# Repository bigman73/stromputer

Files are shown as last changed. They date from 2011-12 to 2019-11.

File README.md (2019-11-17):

# stromputer

V-Strom + Computer --> Stromputer!
An Arduino based project, that adds the following features to a Mk1 (2004-2011) Suzuki V-Strom Motorcycles (DL650, DL1000)

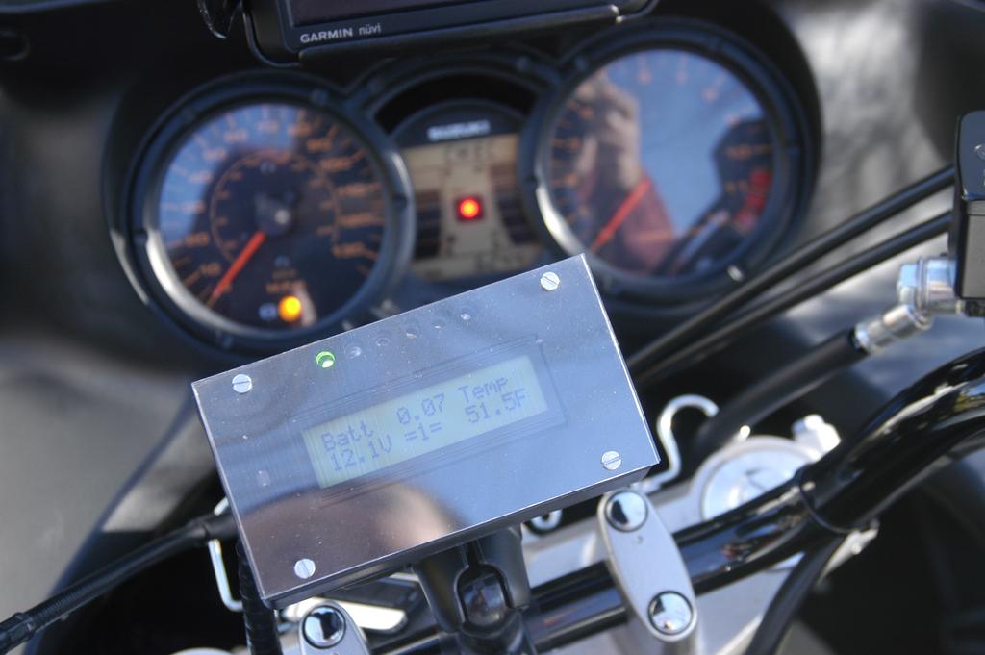
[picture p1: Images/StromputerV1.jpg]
Stromputer V1 installation of a 2011 Suzuki V-Strom 650


## Features

* Auxiliary LCD display that can reside on the handle bar
* Automatic adjustment of LCD display back light using a photo sensor (i.e. at darkness dim LCD display, at full bright day brighten display)
* Show battery level indicator in volts (LCD)
* Show ambient/air temperature (F or C) (LCD)
* Digital LCD Display of gear position
* Analog display of gear position using 6 LEDs
* Configuration and diagnostics shell (command line), with a laptop and USB using Putty or Arduino IDE - can be done while bike is running!
* Upgrade of Firmware through USB port - can also be done while bike is running.
* Modular platform, can be adapted for other motorcycles.

DIY Cost: About $70! (in a full water resistant enclosure)
Compare that to commercial gear indicators/battery indicator/temperature gauges.

Current status: Fully Functional (V1.09 - As of 2/7/2013)

## References
### Brickuino
[Brickuino](http://k75retro.blogspot.com/2014/02/) is a spin off project for BMW K75 Brick motorcycle, based on Stromputer
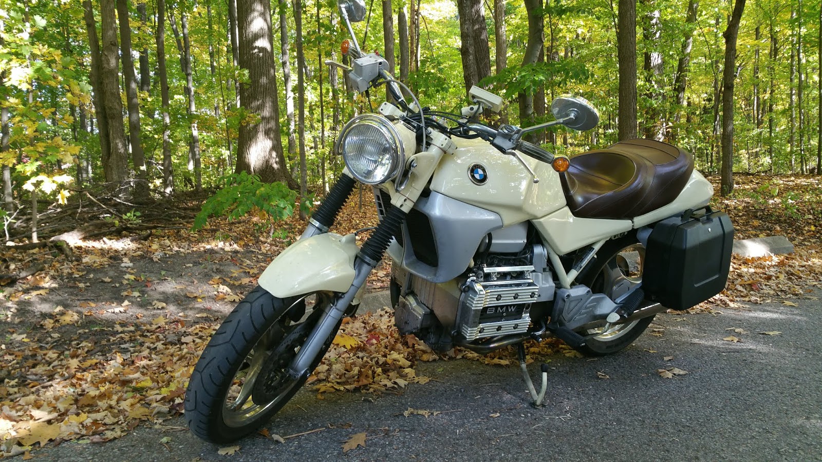
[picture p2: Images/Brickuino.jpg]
Brickuino BMW K75


## License 

Attribution-NonCommercial-ShareAlike 3.0 Unported (CC BY-NC-SA 3.0)

http://creativecommons.org/licenses/by-nc-sa/3.0/

You are free:
to Share — to copy, distribute and transmit the work

to Remix — to adapt the work

Under the following conditions:

+ Attribution — You must attribute the work in the manner specified by the author or licensor (but not in any way that suggests that they endorse you or your use of the work).

+ Noncommercial — You may not use this work for commercial purposes.
Share Alike — If you alter, transform, or build upon this work, you may distribute the resulting work only under the same or similar license to this one.

Creative Commons License

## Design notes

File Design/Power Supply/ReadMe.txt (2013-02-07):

All simulation files were generated using Linear Tech LTspice IV.  LTspice is a very capable analog circuit simulation based on the popular SPICE engine.

http://www.linear.com/designtools/software/

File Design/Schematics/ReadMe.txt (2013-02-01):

************PCB Design Software************************

All files for the PCB design were created in PCB Atrist.  To download this program go to:

http://www.4pcb.com/free-pcb-layout-software/

To view or modify the schematic open "Stromputer V1.sch" from PCB Artist.

To To view or modify the pcb open "Stromputer V1.pcb" from PCB Artist.

*************Component Libraries**********************

The component libraries used is this design were exported to "Stromputer.palib"

To import these components, simply drag and drop the file onto the Components page of the Library Manager dialog, or use the Add File button to browse to where the file is stored.
When you do this, each of the saved 'elements' (Component, PCB Symbols and/or Schematic Symbols) are stored in the special local libraries for Downloaded library items. From there, you can select them and use the Save Items To Library option to copy them to your own library files.

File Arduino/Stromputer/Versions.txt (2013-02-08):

// []
// []     **** Compatible with ARDUINO: 1.03 ****
// []
// []
// []   Versions:
// []     0.07 - Prototype, ADC worksonly with PCF8591
// []     0.08 - Prototype, ADC works with Arudino Analog or PCF8591
// []     0.09 - Prototype, add timed actions - Battery and Temperature should not be polled every loop, just once a few seconds
// []     0.10 - 12/3/2011, Stable Prototype, first version in Google Code/SVN
// []     0.11 - 12/4/2011, Added gear led logic in software, refactored code to use ISR for main board blink and gear neutral blinking led, changed welcome screen
// []     0.12 - 12/5/2011, Added direct gear emulation (tactile button)
// []     0.13 - 12/9/2011, Added gear led boot test. Last version compatible with Arduino 0023 before moving to Arduino 1.0
// []     0.14 - 12/9/2011, + All LED control was changed to use the LED Library,
// []                       + Add force LCD update every 15 seconds (workaround to LCD clearing screen from time to time)
// []                       + Fixed TimedAction to trigger immediately when sketch starts
// []     0.15 - 12/10/2011, + Changed custom Timer ISR to TimerOne library, Refactored all constants and variables to Stromputer.h header file
// []     0.16 - 12/10/2011, + Code refactoring, naming conventions
// []     0.17 - 12/10/2011 + Moved to Arduino 1.0 (.ino), Main loop slowed down to refersh on 4Hz, removed obsolete PCF8591 gear read logic
// []     0.18 - 12/13/2011 + Add Photo Cell read/Automatic LCD Backlight Adjustment
// []     0.19 - 12/24/2011 + Fixed forced refresh, lcd back light value now using average (for smoothing), Fixed temperature error handling
// []     0.20 - 12/25/2011 + LED Dimming, All LED pins changed to PWM
// []     0.21 - 12/26/2011 + Fixed minor bug - Neutral light was 'jumping' while light has been dimming.
// []     0.22 - 12/26/2011 + Adjusted real resistor values
// []     0.23 -   1/8/2012 + Added time action for checking forced LCD refresh, added serial messages when booting, Added initial Serial Input
// []     0.24 -   1/14/2012 + Added Serial Commands, removed serial debug
// []     0.25 -   1/14/2012 + Added Non-Volatile EEPROM configuration (remains after power is shut off, read when rebooting)
// []     0.26 -   1/21/2012 + Fixed I2C Error Handling, more EEPROM configurations
// []     0.27 -   1/22/2012 + Fixed some bugs - ISR was disabled on each serial processing, MILETONE: Successful 2ND deployment to V-Strom
// []     0.28 -   1/23/2012 + Fixed transient/fake Neutral
// []     0.30 -   2/1/2012  + 
// []     0.31 -   3/10/2012 + Fixed gear voltage ranges (measured on bike)
// []     0.40 -   3/29/2012 + Fixed ADC measuring error (battery and on-board temperature). VCC is not 5.0V and can change. Internal volt reference (1.1V) is used as a reference
// []                        + Using RunningAverage library for smoothing reading of input (Battery, Gear, Temperature)
// []     0.42 -   4/12/2012 + Gear ADC finally fixed - Resistors changed to 499KOhm military spec (low PPM, high precision).
// []     0.44 -   4/21/2012 + Restored VREF self learning mechanism
// []     1.00 -   5/20/2012 + Functional, no major issues
// []     1.02 -   8/11/2012 + Fixed gear voltage for 5th and 6h gear, larger gear and battery window sizes
// []     1.03 -   9/16/2012 + Fixed gear voltage
// []     1.04 -   12/15/2012 + Fine tuned LED factors
// []     1.05 -   12/29/2012 + Adaptions to new LCD display module (YwRobot, compatible to LiquidCrystal)
// []     1.06 -   1/17/2013  + Restored VCC calculation, instead of hard coded 5.0V (using Internal 1.1V reference), Moved to Arudino 1.0.3
// []     1.07 -   2/3/2013   + Compilation flags, fixed temperature labels position, fixed DS1631 initialization
// []     1.08 -   2/7/2013   + Added support for Sainsmart LCD Module
// []     1.09 -   2/7/2013   + Gear LEDs are now an option, enabled by the OPT_GEAR_LEDS #define
// []
// [][][][][][][][][][][][][][][][][][][][][][][][][][][][][][][][][][]

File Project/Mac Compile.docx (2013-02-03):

1) download Smart SVN

2) skip all the hokey initial run options. once you get the software open, click: <Project> <Check Out>

3) Paste the SVN url into the Repository field and hit continue

4) You should see this, with the trunk directory highlighted. Click Continue again

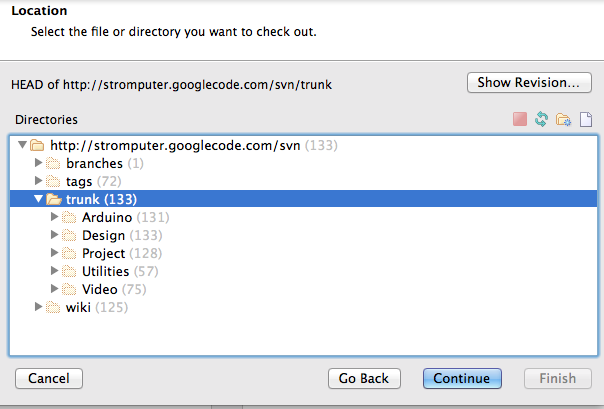
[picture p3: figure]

5)Decide where you want to save it locally.

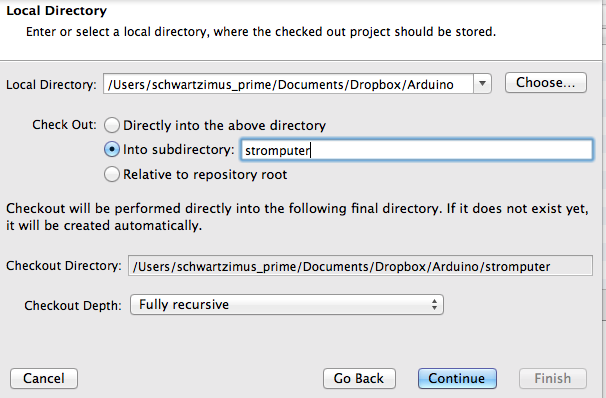
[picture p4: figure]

6) On the last screen, choose Export only since you're just downloading the files from the SVN, not actively working on them.

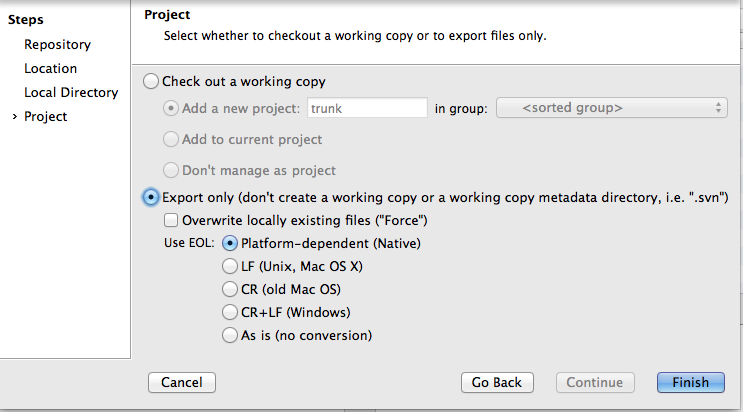
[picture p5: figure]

7) You need to get the included libraries into the proper location on the Mac.

a) Copy all the library folders you got from the SVN

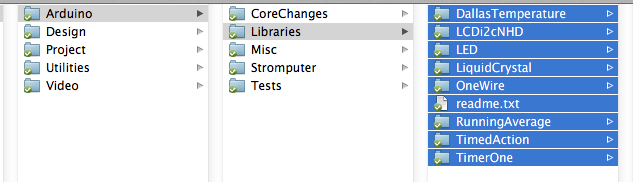
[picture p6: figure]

b) put them into the Mac's hidey-hole location for libraries in Documents/Arduino/Libraries

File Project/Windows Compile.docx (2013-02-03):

# Building Instructions for Stromputer V2

# Introduction

Stromputer V2 will be an improved design (i.e. evolution, not re-design) of Stromputer V1. It focuses on the following factors: 1. Reduced cost 2. Simpler design, less components 3. Smaller form factor

# Install Arduino

1. Download Arduino IDE (1.0+, recommended 1.0.3)

http://arduino.cc/en/Main/Software

1. Unzip the zip into a local folder - e.g. C:\Tools\arduino-1.0.3)

# Source Code Compiling

1. Checkout the code from Google Code: http://code.google.com/p/stromputer/source/checkout, into a local folder (e.g. C:\Development\Stromputer)
2. Delete the Arduino library LiquidCrystal? (http://code.google.com/p/stromputer/w/edit/LiquidCrystal) (e.g. C:\Tools\arduino-1.0.3\libraries\LiquidCrystal? (http://code.google.com/p/stromputer/w/edit/LiquidCrystal))
3. Copy all Stromputer 3rd Party libraries (C:\Development\stromputer\Arduino\Libraries) into Arduino folder (C:\Tools\arduino-1.0.3\libraries)
4. Run Arduino IDE
5. Open Stromputer sketch file (C:\Development\stromputer\Arduino\Stromputer\Stromputer.ino)
6. Compile all code by clicking on the Verify button

## Expected result

Code should compile without errors ("Done Compiling."), the last line in the output should be similar to this one, numbers may vary:

Binary sketch size: 23,688 bytes (of a 30,720 byte maximum)

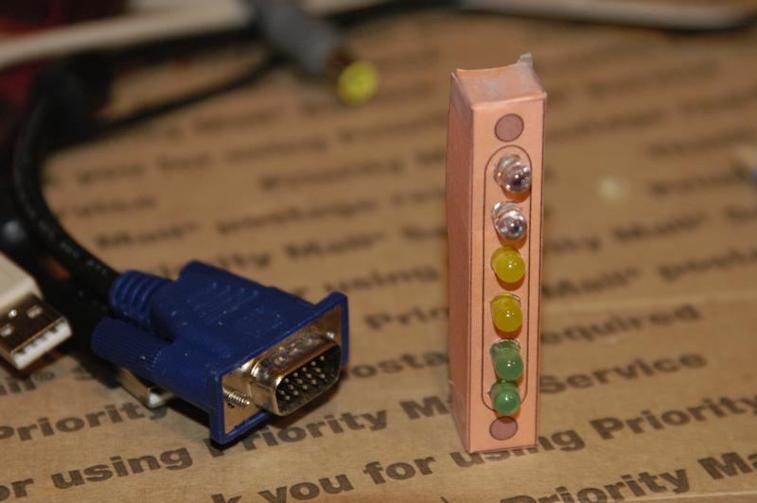
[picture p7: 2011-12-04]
Design/LED Case/mlNP4.jpg

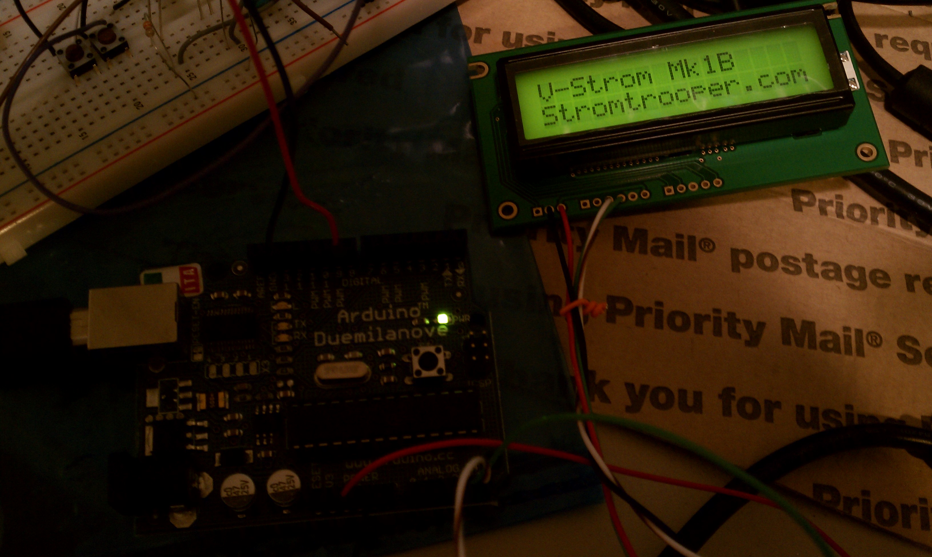
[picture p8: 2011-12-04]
Design/LCD Display/IMAG0272.jpg

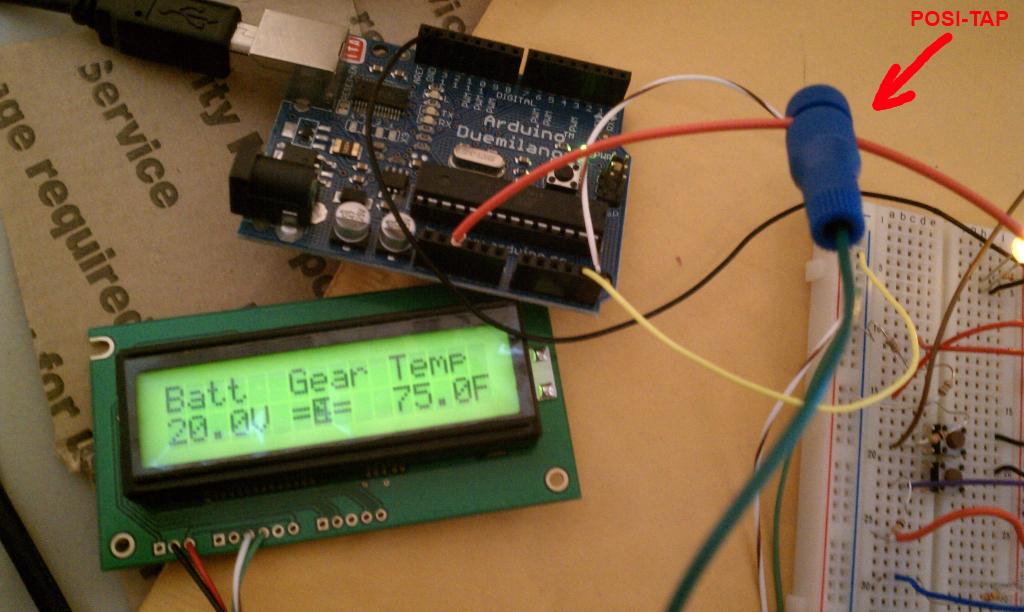
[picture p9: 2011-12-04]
Design/LCD Display/IMAG0290.jpg

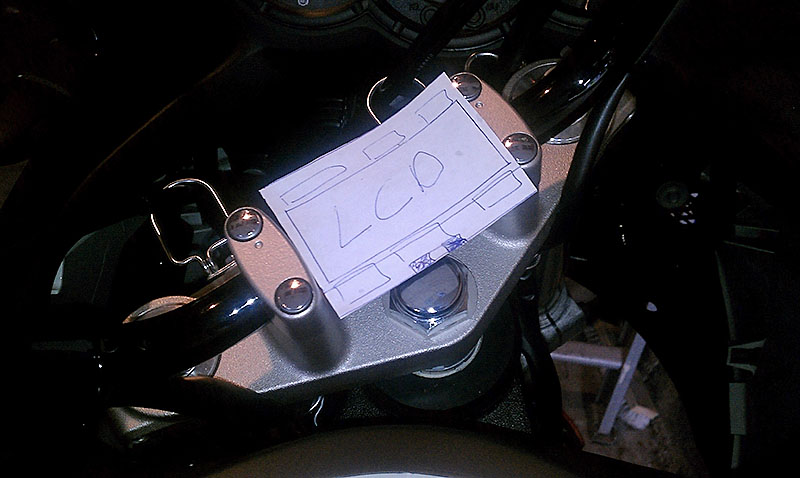
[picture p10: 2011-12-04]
Design/LCD Display/IMAG0016.jpg

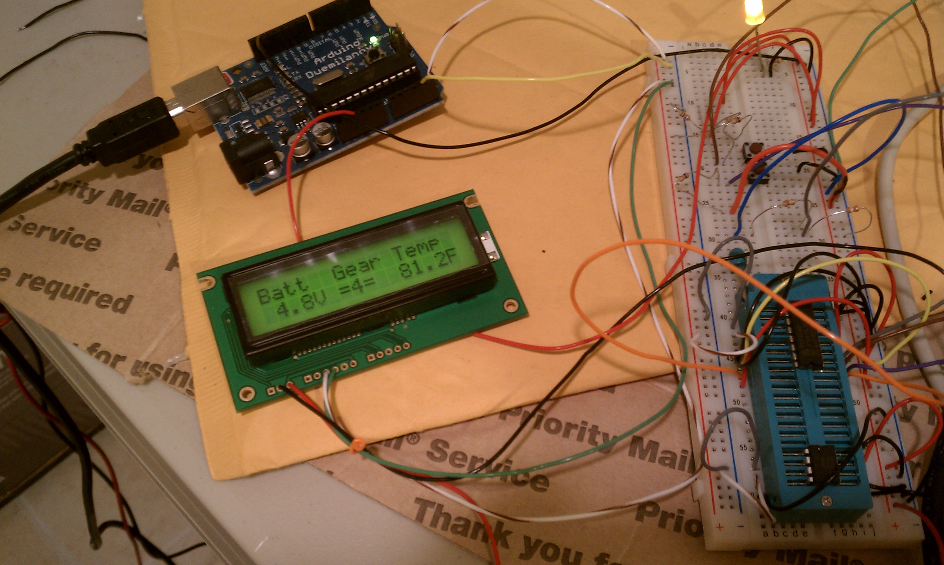
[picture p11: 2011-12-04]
Design/LCD Display/IMAG0280.jpg

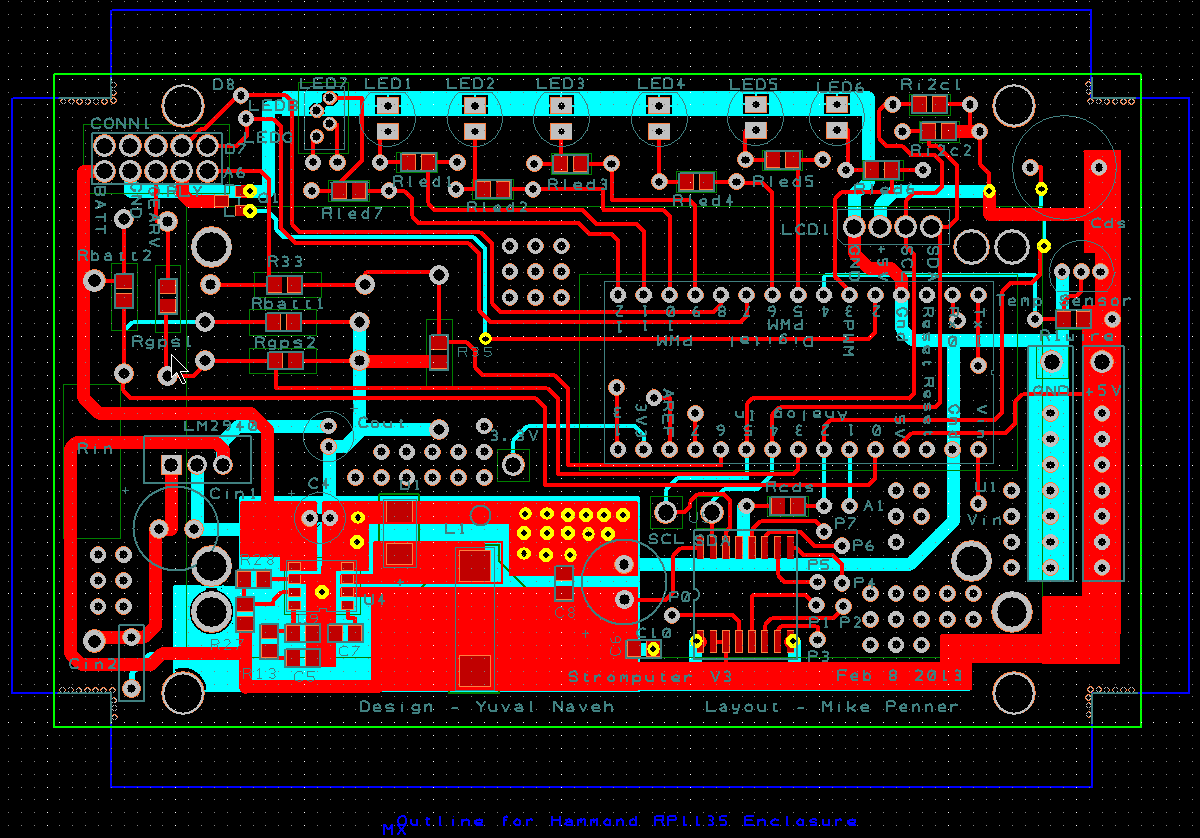
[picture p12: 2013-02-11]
Design/Schematics/PCB Design Stromputer V3.png

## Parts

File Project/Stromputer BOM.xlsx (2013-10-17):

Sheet: V3 (Final)
Component | Value | Manufacturer | Manufacturer Part No | Distributer | Distributer Part No | PCB Ref Name | Qty | Schematic Ref Name | Cost Per Unit | Cost | Notes
Arduino Nano V3 ATMEGA 328 |  |  | Iduino 328 | Amazon or Ebay | ASIN: B00ASSPI60 | U1 | 1 | Nano1 | $12.00 | $12.00 | Iduino is a tested 100% clone of Arduino Nano
10 Pin Header 18 AWG |  |  | -- | Amazon or Ebay | N/A | CONN1 | 1 | -- | $0.00 | $0.00 | Header should come with Iduino
1/8W Resistor | 1k | Stackpole | CF18JT1K00 | Digikey | CF18JT1K00CT-ND | R15 | 1 | Rled1 | $0.09 | $0.09 | LED Resistor
1/8W Resistor | 1k | Stackpole | CF18JT1K00 | Digikey | CF18JT1K00CT-ND | R16 | 1 | Rled2 | $0.09 | $0.09 | LED Resistor
1/8W Resistor | 1k | Stackpole | CF18JT1K00 | Digikey | CF18JT1K00CT-ND | R17 | 1 | Rled3 | $0.09 | $0.09 | LED Resistor
1/8W Resistor | 1k | Stackpole | CF18JT1K00 | Digikey | CF18JT1K00CT-ND | R18 | 1 | Rled4 | $0.09 | $0.09 | LED Resistor
1/8W Resistor | 1k | Stackpole | CF18JT1K00 | Digikey | CF18JT1K00CT-ND | R19 | 1 | Rled5 | $0.09 | $0.09 | LED Resistor
1/8W Resistor | 1k | Stackpole | CF18JT1K00 | Digikey | CF18JT1K00CT-ND | R20 | 1 | Rled6 | $0.09 | $0.09 | LED Resistor
1/8W Resistor | 4.7k | Stackpole | CF18JT4K70 | Digikey | CF18JT4K70CT-ND | R21 | 1 | R1wire | $0.09 | $0.09 | OneWire Pullup Resistor
1/8W Resistor | 4.7k | Stackpole | CF18JT4K70 | Digikey | CF18JT4K70CT-ND | R37 | 1 | Ri2c1 | $0.09 | $0.09 | I2C Pullup Resistor
1/8W Resistor | 4.7k | Stackpole | CF18JT4K70 | Digikey | CF18JT4K70CT-ND | R38 | 1 | Ri2c2 | $0.09 | $0.09 | I2C Pullup Resistor
1/8W Resistor | 10k | Stackpole | CF18JT10K0 | Digikey | CF18JT10K0CT-ND | R14 | 1 | Rcds | $0.09 | $0.09 | Resistor (Voltage Divider)
1/2W Mil Spec Resistor | 953k | Vishay Dale | CMF55953K00BEEB | Digikey | CMF953KHBCT-ND | R23 | 1 | Rbatt2 | $1.53 | $1.53 | Resistor (Voltage Divider)
1/2W Mil Spec Resistor | 332k | Vishay Dale | CMF55332K00BEEB | Digikey | CMF332KHBCT-ND | R26 | 1 | Rbatt1 | $1.12 | $1.12 | Resistor (Voltage Divider)
1/2W Mil Spec Resistor | 499k | Vishay Dale | CMF55499K00BEEB | Digikey | CMF499KHBCT-ND | R24 | 2 | Rgps1, Rgps2 | $1.12 | $2.24 | Resistor (Voltage Divider)
CAPP Pan 8 mm body | 220uF | Panasonic | ECA-1EHG221 | Digikey | P5541-ND | C2 | 1 | Cin1 | $0.45 | $0.45 | Capacitor (Linear Regulator)
CAP TDK Cer Radial | 0.47uF | TDK | FK26X7R1H474K | Digikey | 445-2870-ND | C3 | 1 | Cin2 | $0.48 | $0.48 | Capacitor (Linear Regulator)
CAPP Pan AL 5 mm body | 22uF | Panasonic | EEU-FM1H220 | Digikey | P12927-ND | C1 | 1 | Cout | $0.31 | $0.31 | Capacitor (Linear Regulator)
DS18B20-TO92 |  | Maxim Integrated | DS18B20+T&R | Digikey | DS18B20+T&RCT-ND | U2 | 1 | Temp Sensor | $4.51 | $4.51 | I2C Digital Temperature Sensor
LCD 16x2 NHD |  | NHD | NHD-0216K3Z-FL-GBW-V3 | Digikey | NHD-0216K3Z-FL-GBW-V3-ND | LCD1 | 1 | LCD1 | $19.75 | $19.75 | LCD (I2C). See Note 1 below
LED | Blue | Cree | C503B-BCS-CV0Z0461 | Digikey | C503B-BCS-CV0Z0461-ND | LED6 | 1 | Led1 | $0.21 | $0.21 | BLUE LED - Gear 6
LED | Green | Cree | C503B-GCN-CY0C079 | Digikey | C503B-GCN-CY0C0791-ND | LED1 | 1 | Led2 | $0.24 | $0.24 | GREEN LED - Gear 1
LED | Yellow | Lumex Opto | SSL-LX5093YT | Digikey | 67-1117-ND | LED2 LED3 | 2 | Led3,Led4 | $0.55 | $1.10 | YELLOW LED - Gear 2,3
LED | White | Cree | C503B-WAN-CCACB151 | Digikey | C503B-WAN-CCACB151-ND | LED4 LED5 | 2 | Led5, Led6 | $0.46 | $0.92 | WHITE LED - Gear 4,5
LM2940T-5.0 |  | TI | LM2940T-50 | Digikey | LM2940T-5.0-ND | U3 | 1 | LM2940 | $1.68 | $1.68 | 12V->5V linear voltage regulator
3W Resistor | 16 | Panasonic | ERG-3SJ160 | Digikey | P16W-3BK-ND | R22 | 1 | Rin | $0.59 | $0.59 | Current Limiter Resistor, Linear Regulator
PDV-P8001 |  | Advanced Photonix | PDV-P8001 | Digikey | PDV-P8001-ND | VR1 | 1 | Cds | $1.86 | $1.86 | Photo sensor
Enclosure |  | Hammond | RP1135C | Digikey | RP1135C-ND |  | 1 |  | $8.57 | $8.57 | Water Proof Clear Top Enclosure
Custom PCB |  |  |  | Stromtrooper/Bigman73 |  |  | 1 |  | $15.00 | $15.00
 |  |  |  |  |  |  |  |  | Total cost | $73.46
Notes:
1. There are cheaper LCD modules, e.g. from eBay/Amazon or other internet sources, but they do not support programmatic constast and brightness control.
The SainSmart and YwRobot 1602 I2C modules have been certificed to work with the Stromputer firmware, and the firmware now supports them
LCD 16x2 I2C |  | SainSmart | LCD 1602 I2C | Amazon | ASIN: B00813HBEQ | LCD1 | 1 |  | $13.50 | $13.50 | Alternative to NHD LCD Module

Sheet: V3 (Full All Options)
Component | Package | Value | Manuf | Manuf Part No | Distrib | Distrib Part No | PCB Ref Name | Qty | Schematic Ref Name | Cost Per Unit | Cost | Notes
Arduino Nano V3 ATMEGA 328 | USER |  |  |  | Amazon or Ebay | ASIN: B00ASSPI60 | U1 | 1 | Nano1 | $12.00 | $12.00 | Iduino is a tested 100% clone of Arduino Nano
10 Pin Header 18 AWG | USER |  |  |  | Amazon or Ebay | N/A | CONN1 | 1 |  | $0.00 | $0.00 | Header should come with Iduino
1/8W Resistor | USER | 1k | Stackpole | CF18JT1K00 | Digikey | CF18JT1K00CT-ND | R15 | 1 | Rled1 | $0.09 | $0.09 | LED Resistor
1/8W Resistor | USER | 1k | Stackpole | CF18JT1K00 | Digikey | CF18JT1K00CT-ND | R16 | 1 | Rled2 | $0.09 | $0.09 | LED Resistor
1/8W Resistor | USER | 1k | Stackpole | CF18JT1K00 | Digikey | CF18JT1K00CT-ND | R17 | 1 | Rled3 | $0.09 | $0.09 | LED Resistor
1/8W Resistor | USER | 1k | Stackpole | CF18JT1K00 | Digikey | CF18JT1K00CT-ND | R18 | 1 | Rled4 | $0.09 | $0.09 | LED Resistor
1/8W Resistor | USER | 1k | Stackpole | CF18JT1K00 | Digikey | CF18JT1K00CT-ND | R19 | 1 | Rled5 | $0.09 | $0.09 | LED Resistor
1/8W Resistor | USER | 1k | Stackpole | CF18JT1K00 | Digikey | CF18JT1K00CT-ND | R20 | 1 | Rled6 | $0.09 | $0.09 | LED Resistor
1/8W Resistor | USER | 4.7k | Stackpole | CF18JT4K70 | Digikey | CF18JT4K70CT-ND | R21 | 1 | R1wire | $0.09 | $0.09 | OneWire Pullup Resistor
1/8W Resistor | USER | 4.7k | Stackpole | CF18JT4K70 | Digikey | CF18JT4K70CT-ND | R37 | 1 | Ri2c1 | $0.09 | $0.09 | I2C Pullup Resistor
1/8W Resistor | USER | 4.7k | Stackpole | CF18JT4K70 | Digikey | CF18JT4K70CT-ND | R38 | 1 | Ri2c2 | $0.09 | $0.09 | I2C Pullup Resistor
1/8W Resistor | USER | 10k | Stackpole | CF18JT10K0 | Digikey | CF18JT10K0CT-ND | R14 | 1 | Rcds | $0.09 | $0.09 | Resistor (Voltage Divider)
1/2W Mil Spec Resistor | USER | 953k | Vishay Dale | CMF55953K00BEEB | Digikey | CMF953KHBCT-ND | R23 | 1 | Rbatt2 | $1.53 | $1.53 | Resistor (Voltage Divider)
1/2W Mil Spec Resistor | USER | 332k | Vishay Dale | CMF55332K00BEEB | Digikey | CMF332KHBCT-ND | R26 | 1 | Rbatt1 | $1.12 | $1.12 | Resistor (Voltage Divider)
1/2W Mil Spec Resistor | USER | 499k | Vishay Dale | CMF55499K00BEEB | Digikey | CMF499KHBCT-ND | R24 | 2 | Rgps1, Rgps2 | $1.12 | $2.24 | Resistor (Voltage Divider)
CAPP Pan 8 mm body | USER | 220uF | Panasonic | ECA-1EHG221 | Digikey | P5541-ND | C2 | 1 | Cin1 | $0.45 | $0.45 | Capacitor (Linear Regulator)
CAP TDK Cer Radial | DSC | 0.47uF | TDK | FK26X7R1H474K | Digikey | 445-2870-ND | C3 | 1 | Cin2 | $0.48 | $0.48 | Capacitor (Linear Regulator)
CAPP Pan AL 5 mm body | DSCV | 22uF | Panasonic | EEU-FM1H220 | Digikey | P12927-ND | C1 | 1 | Cout | $0.31 | $0.31 | Capacitor (Linear Regulator)
DS18B20-TO92 | DSC |  | Maxim Integrated | DS18B20+T&R | Digikey | DS18B20+T&RCT-ND | U2 | 1 | Temp Sensor | $4.51 | $4.51 | I2C Digital Temperature Sensor
LCD 16x2 NHD | USER |  | NHD | NHD-0216K3Z-FL-GBW-V3 | Digikey | NHD-0216K3Z-FL-GBW-V3-ND | LCD1 | 1 |  | $19.75 | $19.75 | LCD (I2C)
LED | DSC | Blue | Cree | C503B-BCS-CV0Z0461 | Digikey | C503B-BCS-CV0Z0461-ND | LED6 | 1 |  | $0.21 | $0.21 | BLUE LED - Gear 6
LED | DSC | Green | Cree | C503B-GCN-CY0C079 | Digikey | C503B-GCN-CY0C0791-ND | LED1 | 1 |  | $0.24 | $0.24 | GREEN LED - Gear 1
LED | DSC | Yellow | Lumex Opto | SSL-LX5093YT | Digikey | 67-1117-ND | LED2 LED3 | 2 |  | $0.55 | $1.10 | YELLOW LED - Gear 2,3
LED | DSC | White | Cree | C503B-WAN-CCACB151 | Digikey | C503B-WAN-CCACB151-ND | LED4 LED5 | 2 |  | $0.46 | $0.92 | WHITE LED - Gear 4,5
LM2940T-5.0 | T03B |  | TI | LM2940T-50 | Digikey | LM2940T-5.0-ND | U3 | 1 | LM2940 | $1.68 | $1.68 | 12V->5V linear voltage regulator
3W Resistor | USER | 16 | Panasonic | ERG-3SJ160 | Digikey | P16W-3BK-ND | R22 | 1 | Rin | $0.59 | $0.59 | Current Limiter Resistor, Linear Regulator
PDV-P8001 | USER |  | Advanced Photonix | PDV-P8001 | Digikey | PDV-P8001-ND | VR1 | 1 | Cds | $1.86 | $1.86 | Photo sensor
Enclosure |  |  | Hammond | RP1085C | Digikey | RP1085C-ND |  | 1 |  | $8.57 | $8.57 | Water Proof Clear Top Enclosure
Custom PCB |  |  |  |  | Stromtrooper/Bigman73 |  |  | 1 |  | $11.00 | $11.00 | $5 raw cost + $6 shipping
 |  |  |  |  |  |  |  |  |  | Total cost | $69.46
OPTIONAL - ALTERNATIVE |  | SM |  |  |  | Mouser |  | R35 | 1
 | LED RGB WP154 | USER |  | Kingbright | WP154A4SUREQBFZGC | Digikey | 754-1615-ND | LED7 | 1 |  |  |  | RGB LED
 | LM358 MSOP8 DGK Non Comp Side | MSOP8 DGK |  |  |  |  |  | U7 | 1
 | PCF8574T SOIC16W MS-013 | SM |  |  |  |  |  | U5 | 1 |  |  |  | ADC/DAC I2C extender
 | PCF8591 SOIC16W | SM |  |  |  |  |  | U6 | 1 |  |  |  | IO I2C Extender
 | RES 0805 | SM | 1K | Panasonic | ERA-6AED102V | Mouser | 667-ERA-6AED102V | R1 | 1 | Rled1 Alt
 |  | SM |  | Panasonic | ERA-6AED102V | Mouser | 667-ERA-6AED102V | R2 | 1 | Rled2 Alt
 |  | SM |  | Panasonic | ERA-6AED102V | Mouser | 667-ERA-6AED102V | R3 | 1 | Rled3 Alt
 |  | SM |  | Panasonic | ERA-6AED102V | Mouser | 667-ERA-6AED102V | R4 | 1 | Rled4 Alt
 |  | SM |  | Panasonic | ERA-6AED102V | Mouser | 667-ERA-6AED102V | R5 | 1 | Rled5 Alt
 |  | SM |  | Panasonic | ERA-6AED102V | Mouser | 667-ERA-6AED102V | R6 | 1 | Rled6 Alt
 |  | SM |  | Panasonic | ERA-6AED102V | Mouser | 667-ERA-6AED102V | R31 | 1 | Rled7 Alt
 | RES 0805 | SM | 4.7k | Panasonic | CRCW08054K70JNEA | Mouser | 71-CRCW0805J-4.7K-E3 | R11 | 1 | R1wire Alt
 |  | SM |  | Panasonic | ERJ-6GEYJ472V | Mouser | ERJ-6GEYJ472V | R29 | 1 | Ri2c1 Alt
 |  | SM |  | Panasonic | ERJ-6GEYJ472V | Mouser | ERJ-6GEYJ472V | R30 | 1 | Ri2c2 Alt
 | RES 0805 | SM | 10k | Panasonic | ERJ-6GEYJ103V | Mouser | 667-ERJ-6GEYJ103V | R12 | 1 | Rcds Alt
 | RES 0805 | SM | 12.1k | Panasonic | ERJ-6ENF1212V | Digikey | P12.1KCCT-ND | R28 | 1
 | RES 0805 | SM | 22k | Panasonic | ERJ-6GEYJ223V | Digikey | P22KACT-ND | R13 | 1
 | RES 0805 | SM | 36.5k | Panasonic | ERJ-6ENF3652V | Digikey | P36.5KCCT-ND | R27 | 1
 | RES 0805 | SM | 332k | Panasonic | ERA-6AEB3323V | Mouser | 667-ERA-6AEB3323V | R9 | 1 | Rbatt1 Alt
 | RES 0805 | SM | 499k | Panasonic | ERA-6AEB4993V | Mouser | 667-ERA-6AEB4993V | R7 | 1 | Rgps1 Alt
 |  | SM |  | Panasonic | ERA-6AEB4993V | Mouser | 667-ERA-6AEB4993V | R8 | 1 | Rgps2 Alt
 | RES 0805 | SM | 953k | Panasonic | ERA-6AED9533V | Mouser | 667-ERA-6AED9533V | R10 | 1 | Rbatt2 Alt
 | RES 0805 Non Comp Side | SM |  |  |  |  |  | R39 R40 R41 R42 | 4
 | Si2304BDS MOSFET | USER |  | Vishay | SI2304BDS-T1-GE3 | Digikey | SI2304BDS-T1-GE3CT-ND | Q1 | 1
 | LT1776 SO8N | SM |  | Linear Tech | LT1776CS8#PBF | Digikey | LT1776CS8#PBF-ND | U4 | 1 |  |  |  | Switching voltage regulator
 | MBRS1100 | SM |  | Vishay | MBRS1100TRPBF | Digikey | MBRS1100TRPBFCT-ND | D1 | 1 |  |  |  | Schottky Rectifier (switching regulator)
 | RES 0805 | SM |  |  |  |  |  | R34 | 1
 | 1/8W Resistor | USER | 1k | Stackpole | CF18JT1K00 | Digikey | CF18JT1K00CT-ND | R32 | 1 | Rled7 | 0.09 | $0.09 | Resistor - Optional, not supported as of V2, but will be supported in a future firmware
 |  | DSCV |  | Panasonic | EEU-FM1H220 | Digikey | P12927-ND | C4 | 1 |  |  |  | Capacitor (Switching Regulator)
 | CAP 0805 | SM | 2200 pF | Murata | GRM2165C1H222JA01D | Digikey | Digikey | C5 | 1 |  |  |  | Capacitor (Switching Regulator)
 | CAP 0805 | SM | 2.2 uF | Murata | GRM21BF51A225ZA01L | Digikey | 490-1743-1-ND | C8 | 1 |  |  |  | Capacitor (Switching Regulator)
 | CAP 0805 | SM | 100 pF | Murata | GRM2165C1H101JA01D | Digikey | 490-1615-1-ND | C7 C9 | 2 |  |  |  | Capacitor (Switching Regulator)
 | Ind Bourns SDR1005 | USER | 100 uH | Bourns | SDR1005-101KL | Digikey | SDR1005-101KLCT-ND | L1 | 1 |  |  |  | Inductor (Switching Regulator)
 | CAPP Pan 8 mm body | USER | 220uF | Panasonic | ECA-1EHG221 | Digikey | P5541-ND | C10 | 1 |  |  | $0.00 | Capacitor (Switching Regulator)
 | 1/2W Resistor | USER |  |  |  |  |  | R33 R36 | 2 |  |  | $0.00 | Generic Voltage Divider *Unused*
 | CAP 0805 | SM | 0.1 uF |  |  |  |  | C6 C11 | 2 |  |  | $0.00 | Capacitor - PCF8591/PCF8574
 | CAP 0805 Non Comp Side | SM | 0.1 uF |  |  |  |  | C12 | 1 |  |  | $0.00 | Capacitor (OP-AMP)

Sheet: V2
 | Stromputer BOM (Bill Of Materials) |  | GEN2
 | Number | Description | Schematic Name | Part # | Qty | Unit Price | Price | Link | Purpose
Microcontroller | 1 | Arduino Nano V3 (or compatible) - ATMEGA328P (32K Flash) | Nano1 |  | 1 | $10 | $10.00 | ebay | Brain - Microcontroller
Power Supply | 3 | 16 Ohm current limiter | Rin | DIGIKEY: P16W-3BK-ND | 1 | $0.59 | $0.59 | http://www.digikey.com/product-detail/en/ERG-3SJ160/P16W-3BK-ND/36658 | Part of 12V->5V power regulator
 | 4 | LM2940 5V REGULATOR | LM2940 | DIGIKEY: LM2940T-5.0-ND | 1 | $1.89 | $1.89 | http://www.digikey.com/scripts/DkSearch/dksus.dll?WT.z_header=search_go&lang=en&x=21&y=17&cur=USD | Part of 12V->5V power regulator
 | 5 | Cin1 220uF capacitor | Cin1 | DIGIKEY: P5541-ND | 1 | $0.45 | $0.45 | http://www.digikey.com/scripts/DkSearch/dksus.dll?vendor=0&keywords=P5541-ND | Part of 12V->5V power regulator
 | 6 | Cin2 0.47uF ceramic capacitor | Cin2 | DIGIKEY: 445-2870-ND | 1 | $0.45 | $0.45 | http://www.digikey.com/scripts/DkSearch/dksus.dll?WT.z_header=search_go&lang=en&x=20&y=15&cur=USD | Part of 12V->5V power regulator
 | 7 | Cout 22uF alum capacitor | Cout | DIGIKEY: P12927-ND | 1 | $0.31 | $0.31 | http://www.digikey.com/scripts/DkSearch/dksus.dll?WT.z_header=search_go&lang=en&x=21&y=21&cur=USD | Part of 12V->5V power regulator
LEDs | 8 | Green Clear 5mm LED (for 1st gear) | Led1 | DIGIKEY: C503B-GCN-CY0C0791-ND | 1 | $0.23 | $0.23 | http://www.digikey.com/product-detail/en/C503B-GCN-CY0C0791/C503B-GCN-CY0C0791-ND/1922940 | Gear Position indicator | Note that these are only necessary if you want to color code your gears. If you want to have the same color for all gears then get all the same color LEDs.
 | 9 | Yellow Clear 5mm LED (for 2nd,3rd gears) | Led2, Led3 | DIGIKEY: 365-1183-ND | 2 | $0.19 | $0.38 | http://www.digikey.com/product-detail/en/OVLFY3C7/365-1183-ND/827119 | Gear Position indicator
 | 10 | White Clear 5mm LED (for 4th,5th gears) | Led4, Led5 | DIGIKEY: C503B-WAN-CCACB151-ND | 2 | $0.53 | $1.06 | http://www.digikey.com/scripts/DkSearch/dksus.dll?WT.z_header=search_go&lang=en&x=11&y=13&cur=USD | Gear Position indicator
 | 11 | Blue Clear 5mm LED (for 6th gear) | Led6 | DIGIKEY: C503B-BCS-CV0Z0461-ND | 1 | $0.18 | $0.18 | http://www.digikey.com/product-detail/en/C503B-BCS-CV0Z0461/C503B-BCS-CV0Z0461-ND/1922944 | Gear Position indicator
 | 12 | LED Resistors - 1KOhm, 1/8W | Rled1 .. Rled6 | *Generic | 6 | $0.15 | $0.90 |  | Limit current of Gear Position indicator LEDs
Photo Cell | 13 | PHOTOCELL (CdS) | Cds | DIGIKEY: PDV-P8001-ND | 1 | $1.86 | $1.86 | http://www.digikey.com/scripts/DkSearch/dksus.dll?WT.z_header=search_go&lang=en&x=17&y=15&cur=USD | Measures ambient light to control brightness of backlit LCD display and LEDs
 | 14 | PhotoCell Voltage Divider Resistor - 10KOhm, 1/8W | Rcds | *Generic | 1 | $0.15 | $0.15 |  | Part of PhotoCell circuit
Detect Gear | 15 | Gear Voltage Div Resistors - MilSpec - 499KOhm | Rgps1, Rgps2 | DIGIKEY: CMF499KHBCT-ND | 2 | $1.00 | $2.00 | http://www.digikey.com/product-detail/en/CMF55499K00BEEB/CMF499KHBCT-ND/2197183 | Part of gear voltage meter circuit
Measure Battery | 16 | Battery Voltage Div Resistor 1 - MilSpec - 332KOhm | Rbatt1 | DIGIKEY: CMF332KHBCT-ND | 1 | $1.00 | $1.00 | http://www.digikey.com/product-detail/en/CMF55332K00BEEB/CMF332KHBCT-ND/2197180 | Part of battery voltage meter circuit
 | 17 | Battery Voltage Div Resistor 2 - MilSpec - 953KOhm | Rbatt2 | DIGIKEY: CMF953KHBCT-ND | 1 | $1.00 | $1.00 | http://www.digikey.com/product-detail/en/CMF55953K00BEEB/CMF953KHBCT-ND/2197185 | Part of battery voltage meter circuit
LCD | 18 | I2C LCD Display (16x2) | LCD | EBAY | 1 | $10.00 | $10.00 | http://www.ebay.com/itm/IIC-I2C-TWI-1602-Serial-Shield-Modle-LCD-Display-For-Arduino-MEGA-2560-UNO-A004-/251052650605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 | Main Display
 | 19 | I2C Pull Up Resistors - 4.7KOhm, 1/8W | Ri2c | *Generic | 2 | $0.15 | $0.30 |  | Pulls up the LCD I2C SDA and SCL lines
Temp Sensor | 20 | DS18B20 I2C Temp Sensor | Temperature Sensor | EBAY | 1 | $1.60 | $1.60 | http://www.ebay.com/itm/1-PCS-DS18B20-18B20-Thermometer-Temperature-Sensor-Dalla-/170750980342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 | Digital Temperature Sensor
 | 21 | OneWire Pull Up Resistor - 4.7KOhm, 1/8W | Ronewire | *Generic | 1 | $0.15 | $0.15 |  | Part of digital temperature sensor circuit, pulls up the OneWire line
Hardware | 22 | Enclosure for LCD/LED display |  | DIGIKEY: HM1038-ND | 1 | $6.52 | $6.52 | http://www.digikey.com/scripts/DkSearch/dksus.dll?WT.z_header=search_go&lang=en&x=15&y=14&cur=USD | Enclosure (Box) to hold all components
 | 23 | Posi-Locks - 18-24 AWG (RED) |  | Posi-Lock | 3 | $3.00 | $9.00 | http://www.posi-lock.com/lock2.html | Optional - used to connect/disconnect wires quickly without soldering |  | Note that posi-lock products come in packages. Try to find cheaper single distributions, or buy with other stromtroopers are share the cost
 | 24 | Posi-Tap - 16-18 AWG (BLUE) |  | Posi-Tap | 1 | $9.00 | $9.00 | http://www.posi-lock.com/posiplug.html | Optional - used to tap into the V-Strom GPS (the pink wire)
 | 25 | Radio shack PCB 417 Holes |  | Model: 276-150 | Catalog #: 276-150 | 1 | $2.49 | $2.49 | http://www.radioshack.com/product/index.jsp?productId=2102845 | Circuit board to connect everything together.
 |  |  |  | Total Cost |  |  | $61.51

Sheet: V1 (OBSOLETE)
Stromputer BOM (Bill Of Materials)
Number | Description | Part # | Qty | Unit Price | Price | Link
1 | Arduino Duemilanove | ASIN: B001VK18HC | 1 | $27 | $27.00 | http://www.amazon.com/Arduino-Duemilanove/dp/B001VK18HC
2 | 14V Zener Diode | DIGIKEY: 1N5244B-TPCT-ND | 1 | $0.32 | $0.32
8 | 16Ohm current limiter | DIGIKEY: P16W-3BK-ND | 1 | $0.59 | $0.59
4 | LM2940 9V REGULATOR | DIGIKEY: LM2940T-9.0-ND | 1 | $1.89 | $1.89
5 | Cin1 220uF capacitor | DIGIKEY: P5541-ND | 1 | $0.45 | $0.45
6 | Cin2 0.47uF ceramic capacitor | DIGIKEY: 445-2870-ND | 1 | $0.45 | $0.45
7 | Cout 22uF alum capacitor | DIGIKEY: P12927-ND | 1 | $0.31 | $0.31
8 | Blue Clear 5mm LED (for 6th gear) | DIGIKEY: C503B-BCS-CV0Z0461-ND | 1 | $0.18 | $0.18
9 | Green Clear 5mm LED (for 1st gear) | DIGIKEY: C503B-GCN-CY0C0791-ND | 1 | $0.23 | $0.23
10 | White Clear 5mm LED (for 4th,5th gears) | DIGIKEY: C503B-WAN-CCACB151-ND | 2 | $0.53 | $1.06
11 | Yellow Clear 5mm LED (for 2nd,3rd gears) | DIGIKEY: 67-1117-ND | 2 | $0.40 | $0.80
12 | PHOTOCELL (CdS) | DIGIKEY: PDV-P8001-ND | 1 | $1.86 | $1.86
13 | NHD LCD Display (16x2) | DIGIKEY: NHD-0216B3Z-FL-GBW-ND | 1 | $19.95 | $19.95
14 | DS1631 I2C Temp Sensor | DIGIKEY: DS1631+-ND | 1 | $4.76 | $4.76
15 | Enclosure for LCD/LED display | DIGIKEY: HM1038-ND | 1 | $6.52 | $6.52
16 | Enclosure for Arduino | DIGIKEY: HM107-ND | 1 | $5.12 | $5.12
17 | Ethernet Dual Port | DIGIKEY: A31449-ND | 1 | $3.93 | $3.93
18 | ProtoScrewShield | SparkFun: DEV-09729 | 1 | $14.95 | $14.95 | http://www.sparkfun.com/products/9729
19 | LED Resistors - 1KOhm, 1/8W | * | 6 | $0.15 | $0.90
20 | I2C Pull Up Resistors - 10KOhm, 1/8W | * | 2 | $0.15 | $0.30
21 | PhotoCell Resistor - 10KOhm, 1/8W | * | 1 | $0.15 | $0.15
22 | Battery Voltage Div Resistor 1 - 120KOhm, 1/8W | * | 1 | $0.15 | $0.15
23 | Battery Voltage Div Resistor 2 - 39KOhm, 1/8W | * | 1 | $0.15 | $0.15
24 | Gear Voltage Div Resistors - 33KOhm, 1/8W | * | 2 | $0.15 | $0.30
25 | Plexiglass | ebay | 1 | $5.00 | $5.00
26 | Neoprene Sheet | ebay | 1 | $5.00 | $5.00
27 | Posi-Locks - 18-24 AWG (RED) | Posi-Lock | 3 | $1.00 | $3.00 | http://www.posi-lock.com/lock2.html
*=Generic, Any shop |  | Total |  |  | $105.32
28 | RAM Mount Steel U-Bolt Rail Base with Short Arm Diamond Assembly | SKU:RAMB149-A | 1 | $27.95 | $27.95 | GPSCity
29 | RAM Mount Hardware for Cradles | SKU:RAMSHOL | 1 | $2.80 | $2.80 | GPSCity
30 | Misc - wires, lead, etc. |  |  |  | $15
 |  | Appx Shipping + Tax |  |  | $20
 |  | Actual Total |  |  | $171.07

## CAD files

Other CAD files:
Design/LED Case/LED Case 2.skp

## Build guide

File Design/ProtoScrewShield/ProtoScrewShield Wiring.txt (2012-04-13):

/*
    Stromputer - Enhanced display for Suzuki V-Strom Motorcycles (DL-650, DL-1000, years 2004-2011)
    Copyright (C) 2011 Yuval Naveh

    This program is free software: you can redistribute it and/or modify
    it under the terms of the GNU General Public License as published by
    the Free Software Foundation, either version 3 of the License, or
    (at your option) any later version.

    This program is distributed in the hope that it will be useful,
    but WITHOUT ANY WARRANTY; without even the implied warranty of
    MERCHANTABILITY or FITNESS FOR A PARTICULAR PURPOSE.  See the
    GNU General Public License for more details.

    You should have received a copy of the GNU General Public License
    along with this program.  If not, see <http://www.gnu.org/licenses/>.
*/

/*
 .::::::.:::::::::::::::::::..       ...     .        :::::::::::. ...    :::::::::::::::.,:::::: :::::::..   
;;;`    `;;;;;;;;'''';;;;``;;;;   .;;;;;;;.  ;;,.    ;;;`;;;```.;;;;;     ;;;;;;;;;;;'''';;;;'''' ;;;;``;;;;  
'[==/[[[[,    [[      [[[,/[[['  ,[[     \[[,[[[[, ,[[[[,`]]nnn]]'[['     [[[     [[      [[cccc   [[[,/[[['  
  '''    $    $$      $$$$$$c    $$$,     $$$$$$$$$$$"$$$ $$$""   $$      $$$     $$      $$""""   $$$$$$c    
 88b    dP    88,     888b "88bo,"888,_ _,88P888 Y88" 888o888o    88    .d888     88,     888oo,__ 888b "88bo,
  "YMmMY"     MMM     MMMM   "W"   "YMMMMMP" MMM  M'  "MMMYMMMb    "YmmMMMM""     MMM     """"YUMMMMMMM   "W" 
*/

Battery Voltage Divider (A0) [Blue wire]
-----------------------------
B7:P7 - Jumper Battry (+)/POS  
P6:P4 - RB1 = 39KOhm
P3:M3 (GND) - RB2 = 120KOhm

Gear Voltage Divider (A1)
--------------------------

S7 - Gear Position Sensor wire [Green wire, posi-tapped to Pink wire on V-Strom]
S5:S3 - RG1 = 499Kohm, standing vertically (Ultra High Precision Resistor - Dale CMF55499K00BEEB)
S2:S9 (GND) - RG2  = 499Kohm (Same resistor value as RG1)

[OBSOLETE] Gear Voltage Divider (A1)
--------------------------

Q7 - Gear Position Sensor wire [Green wire, posi-tapped to Pink wire on V-Strom]
Q6:Q4 - RG1 = 10Kohm, standing vertically (Ultra High Precision Resistor - Dale RN55C1002B)
Q3:M4 (GND) - RG2  = 10Kohm (Same resistor as RG1)
Q4:Q5 - JUMPER

Photo Light Sensor/CdS (A2)
----------------------------
Q8 (VDD/5V) - CdS ORANGE-WHITE wire on LAN1, Yellow wire on shield
R7:R9 (GND) - Rcds = 10KOhm
R4 - CdS ORANGE wire on LAN1
R3:R5 - JUMPER

I2C SDA (A4)
-----------------------
T4:T8 - Rsck = 10KOhm (Pull-Up resistor)

I2C SCK (A5)
-----------------------
U4:U8 - Rsda = 10KOhm (Pull-Up resistor)

DS1630 (Temp. I2C Sensor)
----------------------------
R9  - Pin 1 (SDA)
S9  - Pin 2 (SCK)
T9  - Pin 3 (TOUT- Not used)
Y9  - Pin 4 (GND)
Y12 - Pin 5 (ADDR2)
T12 - Pin 6 (ADDR1) 
S9  - Pin 7 (ADDR0) 
R9  - Pin 8 (VDD)

R9:T3 - Grey JUMPER SDA-[PORT A4]
S9:U3 - White/Brown JUMPER SCK-[PORT A5]
U9:U8 - Black JUMPER GND Center Rail
U12:U14 - Black JUMPER A2-GND Right Rail
T12:T14 - Black JUMPER A1-GND Right Rail
S12:S14 - Black JUMPER A0-GND Right Rail
R12:R13 - Red JUMPER VDD-5V Right Rail

OneWire (D4, DS18B20 temp sensor)
-----------------------------
[PORT D4]:Q13 - Rdq = 4.7KOhm (Dq Pull-Up resistor)

Power Supply Unit (14V->9V)
----------------------------
B5 - VCC (BATT)   [Red Wire, 18 Gauage]

B6:C6 Rin - 16 Ohm (standing vertically), C6 Exposed wire leg but insulatd with heat shrink

C5:E5 (C5 = K/BLACK STRIPE, E6 = A): Dz1 - 14.4V

E7:G9 - GND JUMPER 1
J5:L3 - GND JUMPER 2
C7:G7 - VCC JUMPER 1
G5:I5 - VCC Jumper 2

LM2940:
I7: I (Input - 12-20V)
J7: G (GND)
K7: (Output - 9V)

Cin1 - 220uF: E6 -, G6 +

Cin2 - 0.47uF: I6:J6
Cout3 - 22uF: K5 +, L4 -

K6:[VIN PORT] - VIN JUMPER (Purple wire)

SHIELD SCREW IN PORTS:
----------------------
----------------------
LEFT SIDE:
----------
5V      LCD +/LAN1 green
GND     Battery GND
GND     LCD GND/LAN1 blue/black
VIN     Purple Wire
RST     N/C
3V3     N/C
5V      N/C
GND     LAN1 Brown (OneWire GND)
GND     N/C
VIN     N/C
A0      N/C
A1      N/C [A1 inside Was used for Gear Voltage Divider]
A2      N/C
A3      N/C
A4      SDA (I2C DATA),  LAN1 white/blue
A5      SCK (I2C CLOCK), LAN1 white/green
GND     N/C
GND     N/C

RIGHT SIDE:
----------
AREF   N/C
GND    N/C
D13    N/C
D12    N/C
D11    GEAR LED6/LAN2 blue
D10    GEAR LED5/LAN2 white/blue
D9     GEAR LED4/LAN2 white/orange
D8     N/C 
D7     N/C
D6     GEAR LED3/LAN2 orange
D5     GEAR LED2/LAN2 white/green
D4     OneWire DQ (DS18B20)/LAN1 white/brown
D3     GEAR LED1/LAN2 green
D2     N/C
TX     N/C
RX     N/C
GND    LAN2 white/brown
GND    LAN2 brown

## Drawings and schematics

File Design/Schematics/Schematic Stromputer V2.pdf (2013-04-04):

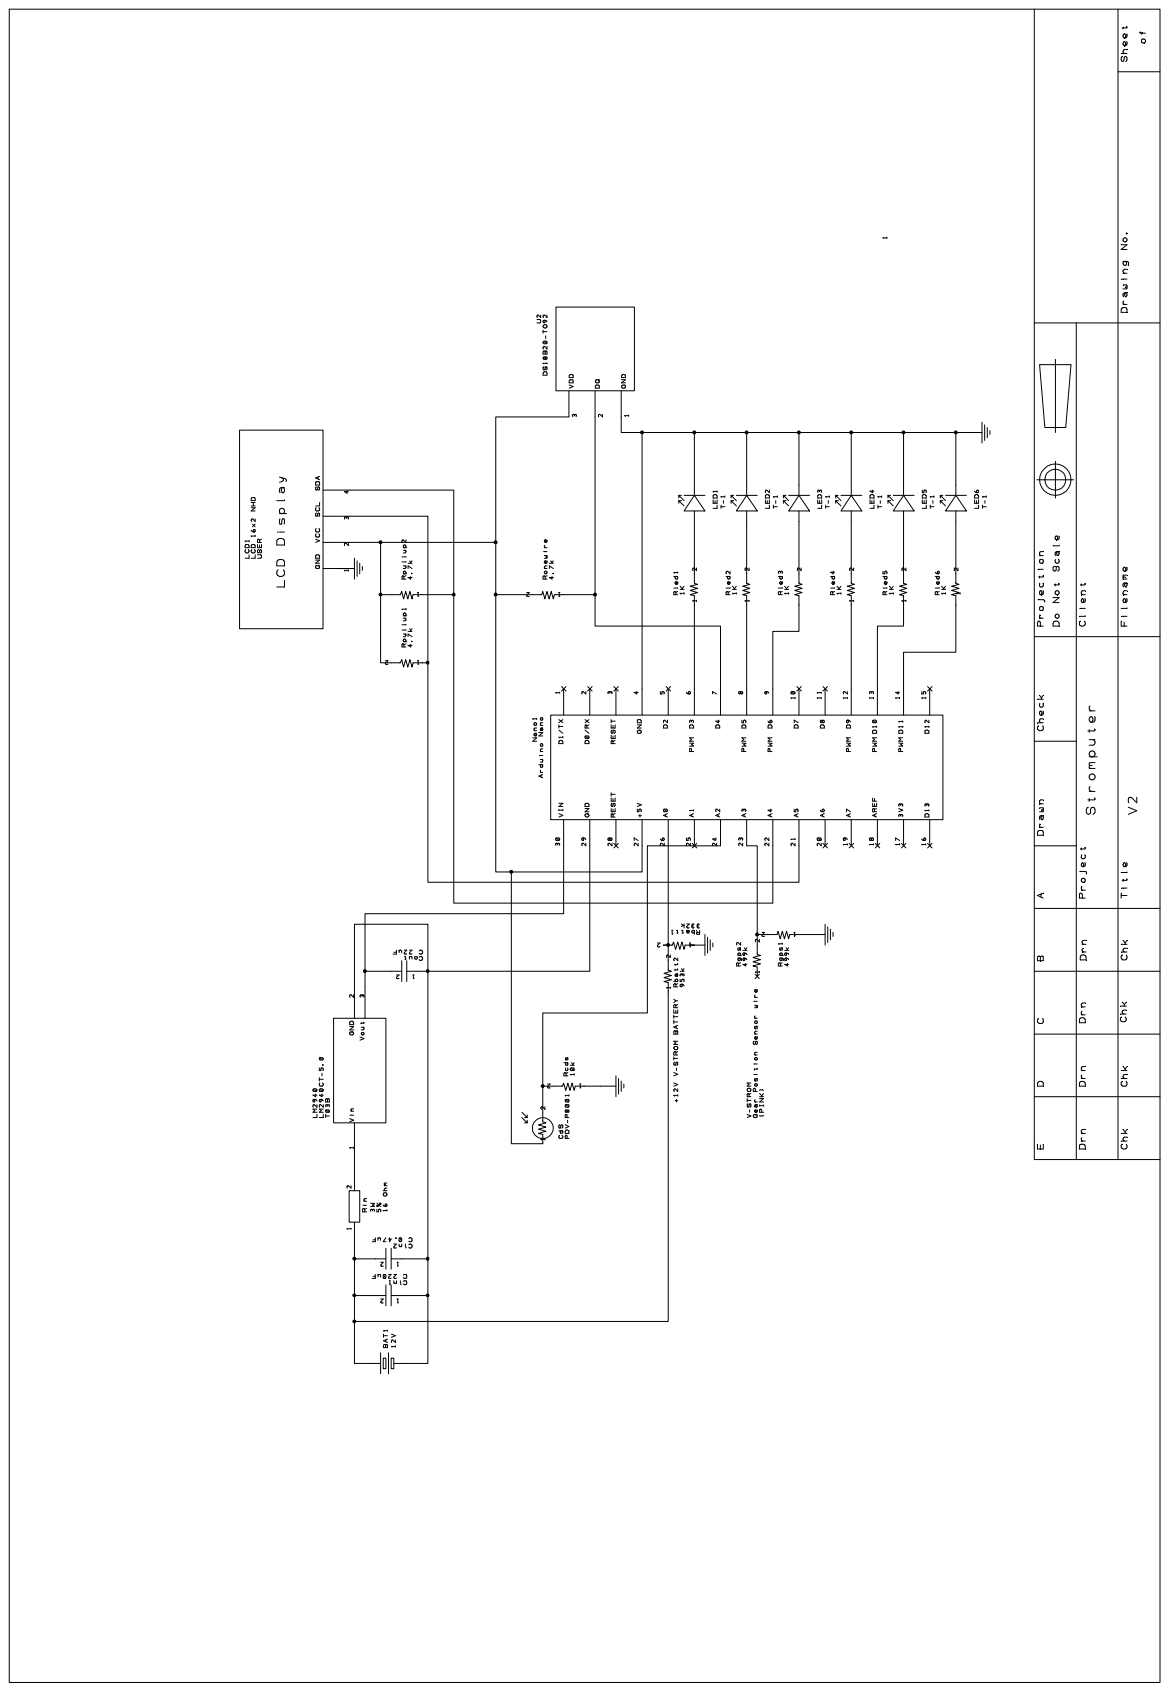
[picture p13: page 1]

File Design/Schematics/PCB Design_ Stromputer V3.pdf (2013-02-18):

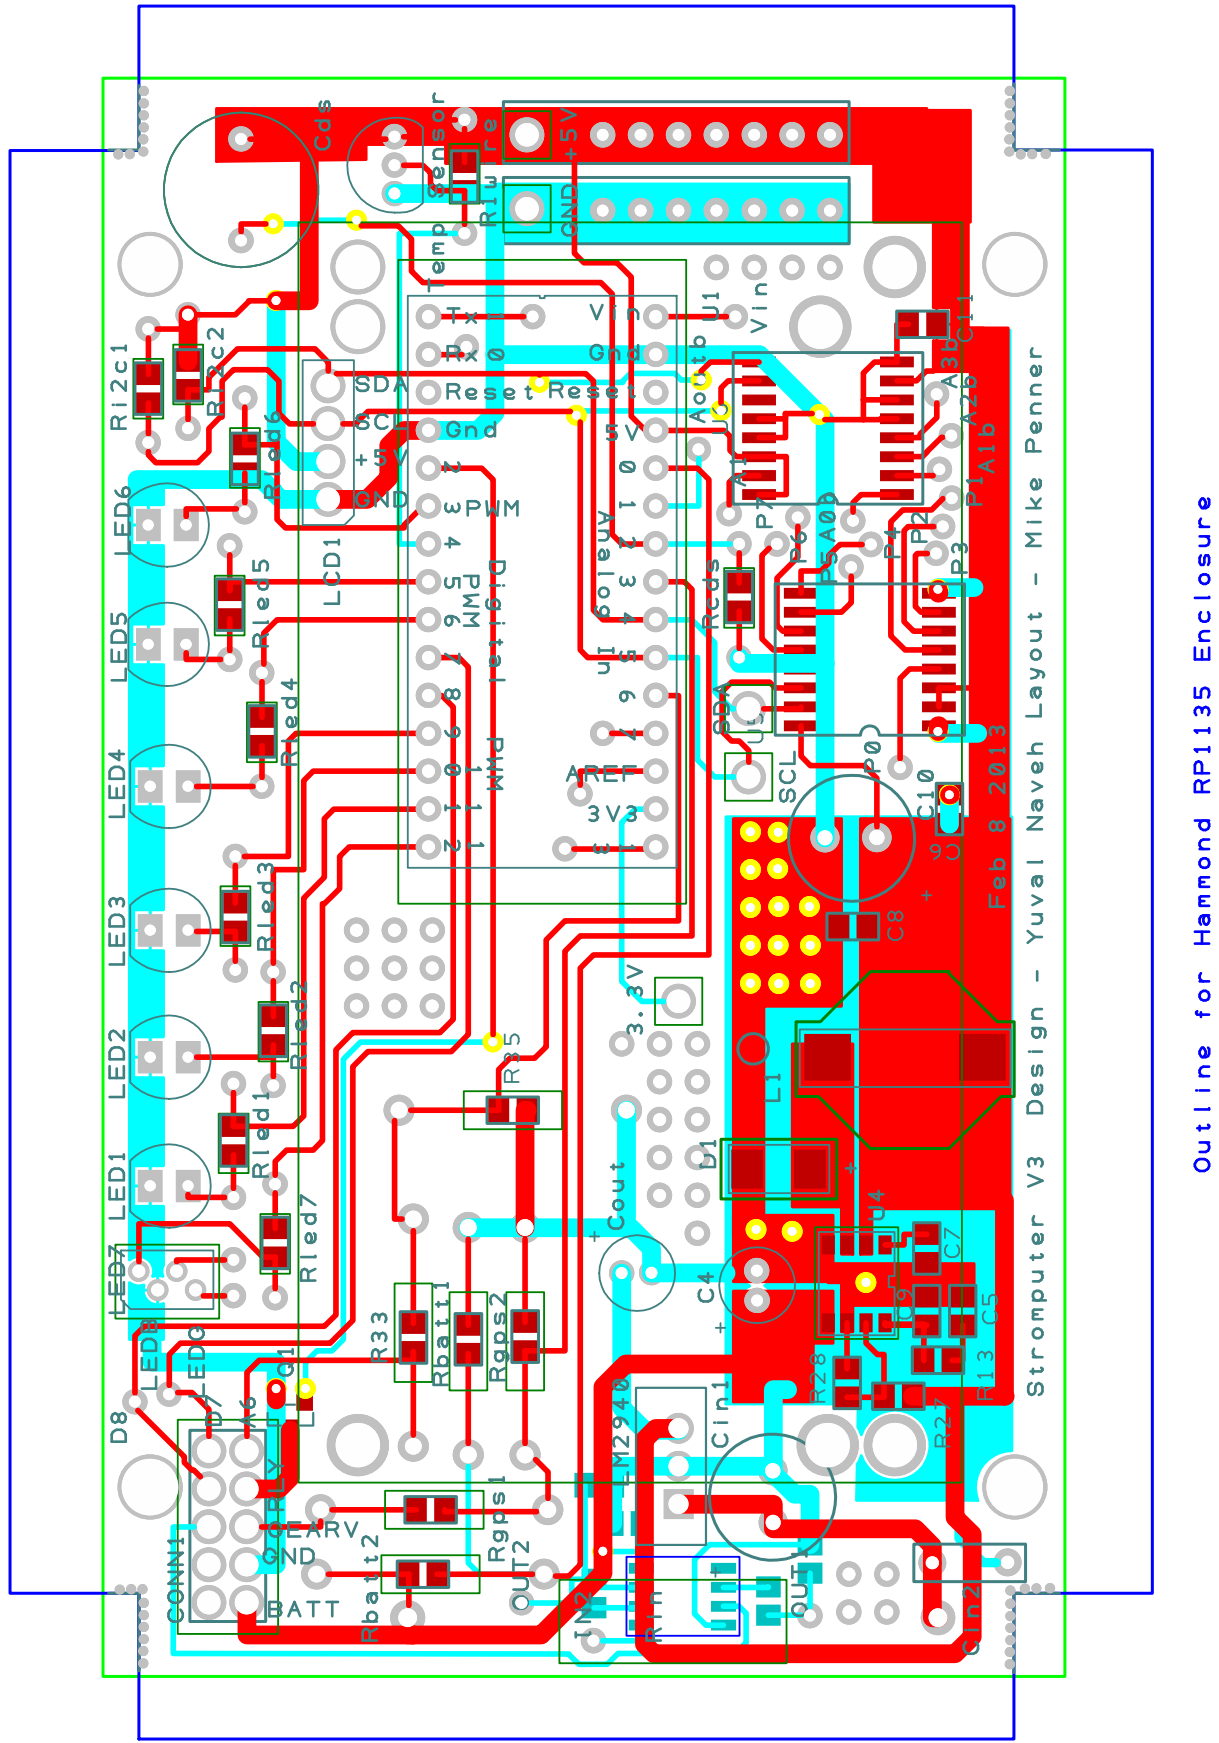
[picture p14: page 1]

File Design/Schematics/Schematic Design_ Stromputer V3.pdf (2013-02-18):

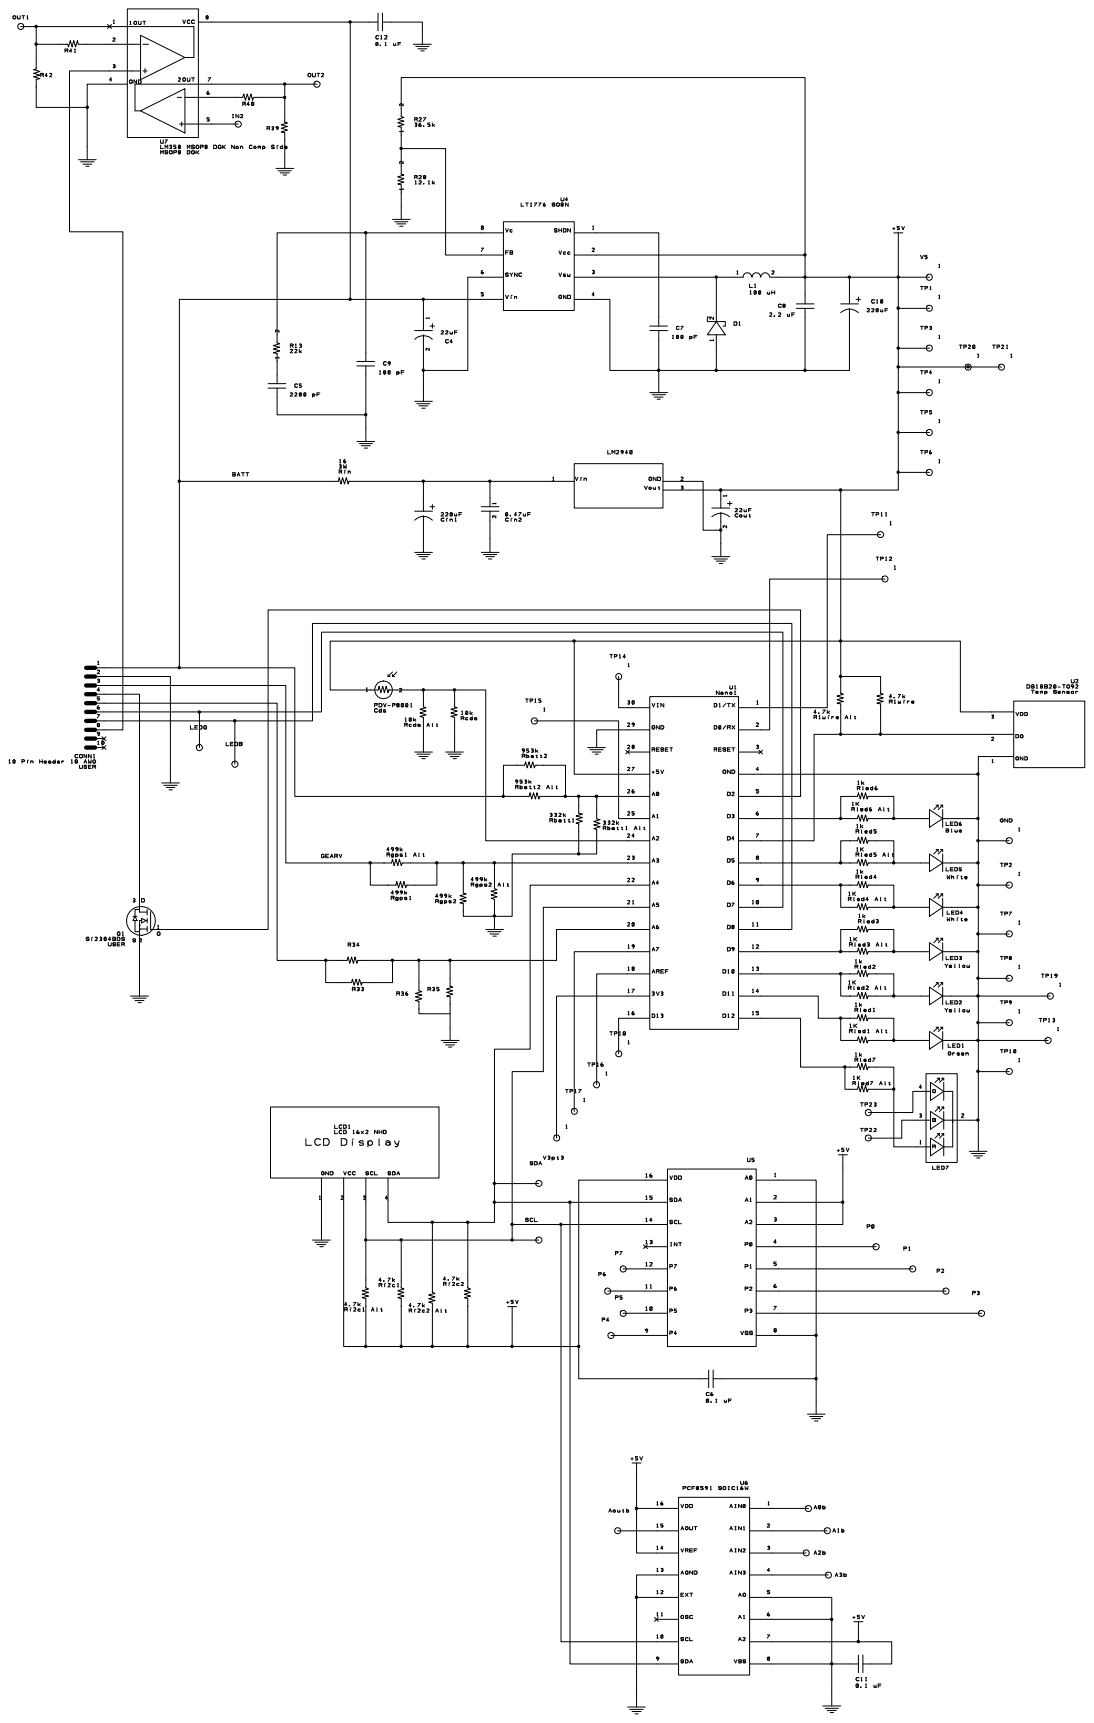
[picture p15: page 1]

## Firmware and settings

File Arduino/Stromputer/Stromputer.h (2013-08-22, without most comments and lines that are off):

#define Stromputer_H
#define VERSION "3.01"
#define OPT_SHOW_WELCOME
#define OPT_GEAR_LEDS
#define DEFAULT_TEMPERATURE_MODE 'F'
#define SERIAL_SPEED_BAUD 38400
#define LCD_ROWS 2
#define LCD_COLS 16
#define DEFAULT_LIGHT_LEVEL 2
byte lightLevel = DEFAULT_LIGHT_LEVEL; // Light level - controls LCD back light (brightness) and LED brightness, ranges from 1..8 (Very Dim..Very Bright)
byte lastLightLevel = DEFAULT_LIGHT_LEVEL;
byte lcdContrast = 50; // 0..50 (no contrast .. high contrast)
bool lcdInitialized = false;
#ifdef LCD_TYPE_NHD
  #define lcd_print_at( row, col, text ) \
     lcd.setCursor(row, col); \
     lcd.print( text );
  #define LCD_I2C_ADDRESS 0x50
  LCDi2cNHD lcd = LCDi2cNHD( LCD_ROWS, LCD_COLS, LCD_I2C_ADDRESS >> 1,0 );
  #define LCD_I2C_NHD_SCROLL_LEFT 0x55
  #define LCD_I2C_NHD_SCROLL_RIGHT 0x56
#elif LCD_TYPE_LIQUIDCRYSTAL
  #define lcd_print_at( row, col, text ) \
     lcd.setCursor(col, row); \
     lcd.print( text );
#ifdef LCD_TYPE_YWROBOT
  #define LCD_I2C_ADDRESS 0x27
#elif LCD_TYPE_SAINSMART
  #define LCD_I2C_ADDRESS 0x3F
#endif
  #define LCD_BACKLIGHT_PIN 3
  #define LCDEXP_EN_PIN 2
  #define LCDEXP_RW_PIN 1
  #define LCDEXP_RS_PIN 0
  #define LCDEXP_D4_PIN 4
  #define LCDEXP_D5_PIN 5
  #define LCDEXP_D6_PIN 6
  #define LCDEXP_D7_PIN 7
  LiquidCrystal_I2C lcd(LCD_I2C_ADDRESS, LCDEXP_EN_PIN, LCDEXP_RW_PIN, LCDEXP_RS_PIN, LCDEXP_D4_PIN, LCDEXP_D5_PIN, LCDEXP_D6_PIN, LCDEXP_D7_PIN);
#endif
#define LCD_ROW_BATT_LABEL    0
#define LCD_COL_BATT_LABEL    0
#define LCD_ROW_BATT_VALUE    1
#define LCD_COL_BATT_VALUE    0
#define LCD_ROW_BACK_LIGHT    0
#define LCD_COL_BACK_LIGHT    4
#define LCD_ROW_GEARVOLTS     0
#define LCD_COL_GEARVOLTS     6
#define LCD_ROW_GEARLABEL     0
#define LCD_COL_GEARLABEL     6
#define LCD_ROW_GEAR          1
#define LCD_COL_GEAR          6
#define LCD_ROW_TEMP_LABEL    0
#define LCD_COL_TEMP_LABEL   11
#define LCD_ROW_TEMP_VALUE    1
#define LCD_COL_TEMP_VALUE   10
#define LCD_ROW_OBTEMP_VALUE  0
#define LCD_COL_OBTEMP_VALUE 10
#define DS1631_I2C_ADDRESS 0x90 >> 1
#define DS1631_I2C_COMMAND_START_CONVERT 0x51
#define DS1631_I2C_COMMAND_STOP_CONVERT 0x22
#define DS1631_I2C_COMMAND_READ_TEMP 0xAA
#define DS1631_I2C_COMMAND_ACCESS_CONFIG 0xAC
#define DS1631_I2C_CONTROLBYTE_CONT_12BIT 0x0C
#define PCF8591_I2C_ADDRESS 0x92 >> 1
#define PCF8591_DAC_SINGLECHANNEL_MODE 0x40
#define PCF8591_MASK_CHANNEL0 1
#define PCF8591_MASK_CHANNEL1 2
#define PCF8591_MASK_CHANNEL2 4
#define PCF8591_MASK_CHANNEL3 8
#define GEAR1_DEFAULT    1.33f
#define GEAR1_FROM_VOLTS 0.00f
#define GEAR2_FROM_VOLTS 1.65f
#define GEAR3_FROM_VOLTS 2.20f
#define GEAR4_FROM_VOLTS 2.90f
#define GEAR5_FROM_VOLTS 3.65f
#define GEAR6_FROM_VOLTS 4.30f
#define GEARN_FROM_VOLTS 4.85f
#define GEARN_TO_VOLTS   5.50f
#define GEAR_NEUTRAL 0
#define GEAR_ERROR -1
#define BUTTON_DOWN 0
#ifdef STROMPUTER_V3_PATCH
  #define ANALOGPIN_BATT_LEVEL A7
  #define ANALOGPIN_GEAR_POSITION A4
  #define ANALOGPIN_PHOTCELL A5
#else
  #define ANALOGPIN_BATT_LEVEL A0
  #define ANALOGPIN_GEAR_POSITION A3
  #define ANALOGPIN_PHOTCELL A2
#endif
#define DIGITALPIN_DS18B20 4
LED ledGears[6] = { LED( 3 ), LED( 5 ), LED( 6 ), \
                    LED( 9 ), LED( 10 ), LED( 11 ) };
byte ledBrightnessGreen = 5;
byte ledBrightnessYellow = 127;
byte ledBrightnessWhite = 127;
byte ledBrightnessBlue = 127;
bool forceLedUpdate = false;
LED onBoardLed = LED();
#define IsBetween( x, a, b ) ( x >= a && x <= b ? 1 : 0 )
#define EEPROM_CONFIG_MEMOFFSET 16
#define EEPROM_STRUCT_VER 10000
struct config_t
{
    int isValidConfig; // Should be >= 10000 || <= 11000 when valid (1000 structure versions allowed)
    char temperatureMode; // F or C
} configuration;
float vcc; // Actual VCC in Volts
byte dac_value=0;     // output 0..255 -> 0-5V (or VSS..VREF)
byte all_adc_values[4];   // Input 0..255 -> 0-5V  (or VSS..VREF)
float ds18b20Temperature = 0;  // Farenheit
float lastTemperature = -99; // Force initial update
bool temperatureReadError = false;
#define MIN_VALID_TEMP -55
short gear = 0;               // 0 = Neutral, or 1-6
long transientGearStartMillis = 0;
short transientGear = GEAR_ERROR;
short lastGearLCD = -2;          // Force initial update
short lastGearLED = -2;       // Force initial update
bool gearReadError = false;
float gearPositionVolts = 0;
float battLevel;             // Volts
float lastBattLevel = -0.1;  // Force initial update
byte battReadError = 0;
short photoCellLevel;
short LoopSleepTime = 5; // msec
bool autoStat = false;
long lastForceLCDRefreshMillis = 0;
bool isForceRefreshBatt = true;
bool isForceRefreshGear = true;
bool isForceRefreshTemp = true;
#define PROCESS_BATT_LEVEL_TIMED_INTERVAL 1000
#define PROCESS_TEMP_TIMED_INTERVAL 2000
#define PROCESS_PHOTO_CELL_TIMED_INTERVAL 3000
#define LCD_DISPLAY_LOOP_TIMED_INTERVAL 250
#define LCD_FORCEREFRESH_INTERVAL 5000
#define SERIALINPUT_TIMED_INTERVAL 100
#define TIMER1_RESOLUTION 1000
#define BATT_VOLT_DIVIDER 4.102f
#define GEAR_VOLT_DIVIDER 2.0f
#define BATT_WINDOW_SIZE 8
#define GEAR_WINDOW_SIZE 12
RunningAverage battRunAvg(BATT_WINDOW_SIZE);
RunningAverage gearLevelRunAvg(GEAR_WINDOW_SIZE);
#define MIN_TRANSIENTGEAR_INTERVAL 200
#define TEMPERATURE_ERROR_DIFF 30
#define TEMPERATURE_MIN_VALID -55
#define PHOTOCELL_LEVEL1 50
#define PHOTOCELL_LEVEL2 250
#define PHOTOCELL_LEVEL3 500
#define PHOTOCELL_LEVEL4 700
#define PHOTOCELL_LEVEL5 800
#define PHOTOCELL_LEVEL6 900
#define PHOTOCELL_LEVEL7 1000
#define EPSILON 0.01
#define CompareFloats( a, b ) abs( a - b ) < EPSILON ? 1 : 0
#define DIRECTION_LEFT 'L'
#define DIRECTION_RIGHT 'R'
#define GEAR_LABEL         "Gear "
#define TEMPERATURE_LABEL  "Temp  "
#define BATTERY_LABEL      "Batt"
#define Welcome1_Line1     "Stromputer-DL650"
#define Welcome1_Line2     "F/W Ver="
#define CMD_ALIVE      "ALIVE"
#define CMD_STAT       "STAT"
#define CMD_AUTOSTAT   "AUTOSTAT"
#define CMD_CONFIG     "CONFIG"
#define CMD_TEST       "TEST"
#define CMD_SETCFG     "SETCFG"
#define CMD_TESTLEDS   "TESTLEDS"
#define CMD_ARG_TEMP   "TEMP"
#define MSG_STROMPUTER_READY     F( ">> Stromputer ON. Ready to Rock! <<" )
#define MSG_FIRMWARE             F( "------- Stromputer, Firmware version: " )
#define MSG_SHOW_ALL_GEAR_LEDS   F( ">> Show all Gear LEDs" )
#define MSG_TEST_EACH_GEAR_LED   F( ">> Test each Gear LED" )
#define MSG_LCD_INIT_BEGIN       F( ">> LCD Initializing.." )
#define MSG_LCD_INIT_END         F( ">> LCD Initialized" )
#define MSG_DS1631_INIT_BEGIN    F( ">> DS1631 Initializing.." )
#define MSG_DS1631_INIT_END      F( ">> DS1631 Initialized" )
#define MSG_WELCOME_BEGIN        F( ">> Show Welcome - BEGIN.." )
#define MSG_WELCOME_END          F( ">> Show Welcome - END" )
#define MSG_SYNTAX_1             F( "SYNTAX: CMD [ARG1] [ARG2];" )
#define MSG_SYNTAX_2             F( "   CMD = {ALIVE | TEST | STAT | SETCFG}" )
#define MSG_ISALIVE              F( "Yes, I'm here" )
#define ERR_LCD_INIT_FAILED      F( ">> ERROR: LCD failed to initialize" )
#define ERR_DS1631_INIT_FAILED   F( ">> ERROR: DS1631 failed to initialize" )
#define UNIT_VOLT "V"
#define NOTAVAIL "X"

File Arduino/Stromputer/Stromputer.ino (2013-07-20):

// [][][][][][][][][][][][][][][][][][][][][][][][][][][][][][][][][][]
// []
// []   Stromputer - An enhanced display for a Suzuki DL-650 ("V-Strom") that adds the following functions:
// []	  1. Battery Level display in Volts - e.g. 14.5V
// []	  2. Gear Position Indicator on LCD - e.g. 1, 2, 3, 4, 5, 6, N
// []	  3. Ambient Temperature in Farenheight or Celsius - e.g. 62.5F
// []	  4. LED display of gear position (one led for each gear 1-6, in different colors, N will be blinking on 1)
// []	  5. [Future] Accurate display of the fuel level (in percentage)
// []     6. [Future] Show Fuel consumption - MPG or KM/L, TBD: need to tap into motorcycle's speed sensor (PWM)
// []	  7. [Future] Fix the OEM V-Strom Fuel Gauge to become linear
/*
    Stromputer - Enhanced display for Suzuki V-Strom Motorcycles (DL-650, DL-1000, years 2004-2011)
    Copyright (C) 2011 Yuval Naveh
    
    >> This work is licensed under a Creative Commons Attribution-NonCommercial-ShareAlike 3.0 Unported License: by-nc-sa <<    
    http://creativecommons.org/licenses/by-nc-sa/3.0/legalcode

    You are free:

      to Share — to copy, distribute and transmit the work
      to Remix — to adapt the work

    Under the following conditions:

      Attribution — You must attribute the work in the manner specified by the author or licensor (but not in any way that suggests that they endorse you or your use of the work).
      Noncommercial — You may not use this work for commercial purposes.
      Share Alike — If you alter, transform, or build upon this work, you may distribute the resulting work only under the same or similar license to this one.
*/

/*
 .::::::.:::::::::::::::::::..       ...     .        :::::::::::. ...    :::::::::::::::.,:::::: :::::::..   
;;;`    `;;;;;;;;'''';;;;``;;;;   .;;;;;;;.  ;;,.    ;;;`;;;```.;;;;;     ;;;;;;;;;;;'''';;;;'''' ;;;;``;;;;  
'[==/[[[[,    [[      [[[,/[[['  ,[[     \[[,[[[[, ,[[[[,`]]nnn]]'[['     [[[     [[      [[cccc   [[[,/[[['  
  '''    $    $$      $$$$$$c    $$$,     $$$$$$$$$$$"$$$ $$$""   $$      $$$     $$      $$""""   $$$$$$c    
 88b    dP    88,     888b "88bo,"888,_ _,88P888 Y88" 888o888o    88    .d888     88,     888oo,__ 888b "88bo,
  "YMmMY"     MMM     MMMM   "W"   "YMMMMMP" MMM  M'  "MMMYMMMb    "YmmMMMM""     MMM     """"YUMMMMMMM   "W" 
*/

#define STROMPUTER_V3_PATCH

// ================================================================================================
// ==> Select your LCD type here: Only ONE define should be active from the LCD_TYPE_* defines
// #define LCD_TYPE_NHD 1
#define LCD_TYPE_YWROBOT 1
// #define LCD_TYPE_SAINSMART 1


// --------------------------------
#if defined(LCD_TYPE_YWROBOT) || defined(LCD_TYPE_SAINSMART)
  #define LCD_TYPE_LIQUIDCRYSTAL 1
#endif  
// ================================================================================================

// -----------------    Library Includes    ------------------------

#ifdef LCD_TYPE_NHD

  // Include 3rd Party library - LCD I2C NHD
  // http://www.arduino.cc/playground/Code/LCDi2c
  #include <LCDi2cNHD.h>                    
#elif LCD_TYPE_LIQUIDCRYSTAL

  // Include 3rd Party library - LCD Crystal I2C 
  #include <LCD.h>
  #include <LiquidCrystal_I2C.h>                    

#endif

// Include 3rd Party library - Timed Actions (Modified by Yuval Naveh)
// http://www.arduino.cc/playground/Code/TimedAction
#include <TimedAction.h>

// Include 3rd Party library - LED (Modified by Yuval Naveh)
// http://arduino.cc/playground/Code/LED
#include <LED.h>

// Include 3rd Party library - TimerOne, used for Timer ISR
// http://arduino.cc/playground/Code/Timer1
#include <TimerOne.h>

// EEPROM support
#include <EEPROM.h>
// EEProm Anything: http://arduino.cc/playground/Code/EEPROMWriteAnything
#include "EEPROMAnything.h"

// 1-Wire Support (Dallas Semiconductor Serial Communication Protocol)
// http://www.pjrc.com/teensy/td_libs_OneWire.html
#include <OneWire.h>

// Dallas Temperature (i.e. DS18B20) support
// https://code.google.com/p/dallas-temperature-control-library/
#include <DallasTemperature.h>

#include <RunningAverage.h>

#include "Stromputer.h"

// -----------------------------------------------------------------

// Other References/Credits:
// DS1631: http://www.arduino.cc/cgi-bin/yabb2/YaBB.pl?num=1221926830
// ISR: http://letsmakerobots.com/node/28278
// Light Sensors: http://www.ladyada.net/learn/sensors/cds.html

// ---------------- Timed Actions (Scheduled re-occouring Events) -------------

// Timed action for forced LCD update
TimedAction checkForceLCDRefreshTimedAction = TimedAction( 0, LCD_FORCEREFRESH_INTERVAL / 2 , checkForceLCDRefresh );

// Timed action for processing battery level
TimedAction battLevelTimedAction = TimedAction( 0, PROCESS_BATT_LEVEL_TIMED_INTERVAL , processBatteryLevel );
// Timed action for processing temperature
TimedAction temperatureTimedAction = TimedAction( 0, PROCESS_TEMP_TIMED_INTERVAL, processTemperature );
// Timed action for processing photo cell light 
TimedAction photoCellTimedAction = TimedAction( 0, PROCESS_PHOTO_CELL_TIMED_INTERVAL, processPhotoCell );
// Timed action for Sampling & LCD Display
TimedAction lcdDisplayTimedAction = TimedAction( 0, LCD_DISPLAY_LOOP_TIMED_INTERVAL, lcdDisplayLoop );

// Timed action for Serial Input
TimedAction serialInputTimedAction = TimedAction( 0, SERIALINPUT_TIMED_INTERVAL, processSerialInput );

OneWire oneWire( DIGITALPIN_DS18B20 );
DallasTemperature DS18B20Sensor( &oneWire ); 

// Include 3rd Party library - Needed for communication with DS1631
#ifdef OPT_USE_DS1631
  #include <Wire.h>
#endif


// IMPORTANT - Needed for using SoftI2C, the V3 PCB (1st Batch) was designed and printed with the analog pins in reverse order (A7..A0) instead of (A0..A7)
#ifdef STROMPUTER_V3_PATCH
  #include <SoftI2C.h>                    
#endif

/// --------------------------------------------------------------------------
/// Arduino one-time setup routine - i.e. Program entry point like main()
/// --------------------------------------------------------------------------
void setup() 
{ 
    // Setup Serial connection
    Serial.begin( SERIAL_SPEED_BAUD );
    Serial.print( MSG_FIRMWARE ); Serial.println( VERSION );

    onBoardLed.on();    
	
    // Setup all input pins
    pinMode(ANALOGPIN_BATT_LEVEL, INPUT);        // Set Battery pin for Input Mode
    digitalWrite(ANALOGPIN_BATT_LEVEL, LOW);     // Disable pullup on analog pin of battery level
    pinMode(ANALOGPIN_PHOTCELL, INPUT);          // Set Photocell pin for Input Mode
    digitalWrite(ANALOGPIN_PHOTCELL, LOW);       // Disable pullup on analog pin of Photo Cell
    pinMode(ANALOGPIN_GEAR_POSITION, INPUT);     // Set Gear Position pin for Input Mode
    digitalWrite(ANALOGPIN_GEAR_POSITION, LOW);  // Disable pullup on analog pin of Gear Position
        
    analogReference(DEFAULT);   // Use 5V Reference for analogRead (ADC)
    
    vcc = readVcc();
    printVcc();
    
    // Start Temperature interface
    DS18B20Sensor.begin();                   
    
    setupConfiguration();

    if ( !initializeLCD() )
    {
        Serial.println( ERR_LCD_INIT_FAILED );
    }

    showWelcome();
   
#ifdef OPT_USE_DS1631   
    if ( !initializeDS1631() )
    {
        Serial.println( ERR_DS1631_INIT_FAILED );
    }
#endif    
    	
    // set Timer1
    Timer1.initialize( TIMER1_RESOLUTION );
    Timer1.attachInterrupt( timerISR ); // attach the service routine here
 
    battLevelTimedAction.force();
    temperatureTimedAction.force();
    photoCellTimedAction.force();
    
    forceLCDRefresh( true );
     
    Serial.println( MSG_STROMPUTER_READY );
}


/// --------------------------------------------------------------------------
/// Arduino loop routine - gets called all the time in an infinite loop
/// --------------------------------------------------------------------------
void loop()
{
    serialInputTimedAction.check();
    lcdDisplayTimedAction.check();
    
    delay(LoopSleepTime);
}

/// --------------------------------------------------------------------------
/// Timed Action Event handler for Sampling & LCD Display Loop 
/// --------------------------------------------------------------------------
void lcdDisplayLoop()
{   
    // Timed Actions ("Events")
    checkForceLCDRefreshTimedAction.check();
    battLevelTimedAction.check();       
    temperatureTimedAction.check();
    photoCellTimedAction.check();

    #ifdef PCF8591_DAC_GEAR_EMULATOR
    // NOTE: DEBUG MODE ONLY - AUTO INCREMENTS EMULATOR OUTPUT VOLTAGE (Used for gear emulation)
    dac_value += 3;
    controlPCF8591_I2C( dac_value, all_adc_values, PCF8591_MASK_CHANNEL0 ); // Output DAC, ADC from channel 1
    #endif
    
    printGearPosition();
}

unsigned short int timerDivider = 0;
bool disableTimerISR = false;

/// --------------------------------------------------------------------------
/// Timer compare Interrupt Service Routine (ISR)
/// Note: Setup to run on 1Khz (1msec)
/// --------------------------------------------------------------------------
void timerISR()
{
    if ( disableTimerISR )
        return;
    
    // Handle main board blinking at 1Hz for each toggle
    if ( timerDivider % 1000 == 1 ) 
    {
        /// Toggle the Main Board LED
        onBoardLed.toggle();
    }

    if ( timerDivider % 1000 == 1 ) 
    {
        vcc = readVcc();
    }
    
    // Handle gear LED display at 20Hz (i.e. check every 50 msec)
    if ( timerDivider % 50 == 1 ) 
    {
        // Read the gear position analog value 
        readGearPositionAnalog();          

#ifdef OPT_GEAR_LEDS
        // Update Gear Position LEDs (note: updateGearLEDs() is optimized to only actually refresh on gear change)
        updateGearLEDs();
#endif        
    }
    
#ifdef OPT_GEAR_LEDS
    // Handle neutral gear blinking, at 4Hz for each toggle
    if ( timerDivider % 250 == 1  && 
         gear == GEAR_NEUTRAL )
    {
        // Toggle 1st Gear LED On/Off (using PWM) , signaling the rider that the gear is N
        // Note: LED::Toggle() doesn't work well, because it uses digitalWrite instead of analogWrite, thus doesn't use PWM and causes the LED to show with full brightness always
        ledGears[ 0 ].setValue( ledGears[ 0 ].getState() ? 0 : ledBrightnessGreen ); // If last state was true, toggle it to true, and visa versa
    }        
#endif        

    timerDivider++;
}

/// --------------------------------------------------------------------------
/// Timed Action Event handler for checkForceLCDRefreshTimedAction - 
///     Triggers a full screen refresh of the NHD LCD 
/// --------------------------------------------------------------------------
void checkForceLCDRefresh()
{
    forceLCDRefresh( false );
}

/// --------------------------------------------------------------------------
/// Force LCD Refresh
/// --------------------------------------------------------------------------
void forceLCDRefresh( bool forceNow )
{
    // Force full screen LCD refresh every X seconds (some unknown bug with NHD LCD causes it to clear the screen from time to time)
    if ( forceNow || ( millis() - lastForceLCDRefreshMillis > LCD_FORCEREFRESH_INTERVAL ) )
    {
        isForceRefreshTemp = true;
        isForceRefreshBatt = true;
        isForceRefreshGear = true;
        lastForceLCDRefreshMillis = millis();
        
        // Force the timed actions to run
        battLevelTimedAction.force(); 
        temperatureTimedAction.force();
        photoCellTimedAction.force();
    }
}

/// --------------------------------------------------------------------------
/// Timed Action Event handler for battLevelTimedAction - 
///     Processes the battery level
/// --------------------------------------------------------------------------
void processBatteryLevel()
{   
    readBatteryLevelAnalog();
    
    /*
    // When 'live' on the motorcycle, there is a difference between what Arduino samples and what a volt meter samples.
    // TODO: Figure out the difference, probably due to a diode somewhere
    // As a temporary workaround, a constant is added
    if ( battLevel > 1.5f )
        battLevel += 0.8f;*/
    
    printBatteryLevel();
}

/// ----------------------------------------------------------------------------------------------------
/// Reads the current battery level from the voltage divider circuit (4:1, 20V -> 5V), using Arduino ADC
/// ----------------------------------------------------------------------------------------------------
void readBatteryLevelAnalog()
{
    battReadError = true; // Assume read had errors, by default

    int rawValue = analogRead( ANALOGPIN_BATT_LEVEL );    // read the input pin for Battery Level
    
    float currentBattLevel = BATT_VOLT_DIVIDER * vcc * ( rawValue / 1024.0f );
    currentBattLevel = constrain( currentBattLevel, 0.01f, 20.0f );

    // Trim the battery level average when the switch is turned on for the first time
    if ( currentBattLevel > 8.f && battLevel < 2.0f )   
    {
        battRunAvg.trimToValue( currentBattLevel );
    }
    // Regular operation
    else
    {
        // Update the moving average window
        battRunAvg.addValue( currentBattLevel );    
    }

    battLevel = battRunAvg.getAverage();
        
    battReadError = false; // Clear read error - we made it here
    
}

/// ----------------------------------------------------------------------------------------------------
/// Print the current battery level (only if there has been a changed)
/// ----------------------------------------------------------------------------------------------------
void printBatteryLevel()
{
    if ( isForceRefreshBatt )
    {
           isForceRefreshBatt = false;
    }
    else
    {
        // Optimization: Don't print the battery level if nothing has changed since the last printing
        if ( !battReadError && ( CompareFloats( lastBattLevel, battLevel )  ) )
        {
            return;
        }
    }
    
    // Keep the current battery level, to optimize display time
    lastBattLevel = battLevel;

    // Print Battery Label
    lcd_print_at(LCD_ROW_BATT_LABEL, LCD_COL_BATT_LABEL, BATTERY_LABEL );  
    
    // Print Battery Value
    String battLevelValue = NOTAVAIL;
    
    if ( battReadError )
    {
        battLevelValue = "ERR  ";
    }
    else
    {
        // Format battery float value
        char formattedBattLevel[5]; // DD.D + NULL => Maximum 5 characters
        dtostrf(battLevel, 4, 1, formattedBattLevel );
        battLevelValue = formattedBattLevel;

        // Add volts unit
        battLevelValue += UNIT_VOLT;
    }
      
    lcd_print_at(LCD_ROW_BATT_VALUE, LCD_COL_BATT_VALUE, battLevelValue );  
}

/// --------------------------------------------------------------------------
/// Timed Action Event handler for photoCellTimedAction - 
///     Processes the photo cell level and adjust LCD Back Light accordingly
/// --------------------------------------------------------------------------
void processPhotoCell()
{   
    readPhotoCellAnalog();
   
    if ( photoCellLevel == 0 ) // Error - CdS is 0 only when sensor is not working
        lightLevel = DEFAULT_LIGHT_LEVEL; // Default
    // Determine new LCD Back Light level (1..8, 1 is very dim .. 8 is very bright)
    else if ( photoCellLevel < PHOTOCELL_LEVEL1 )
        lightLevel = 1; // Very dim
    else if ( photoCellLevel < PHOTOCELL_LEVEL2 )
        lightLevel = 2;
    else if ( photoCellLevel < PHOTOCELL_LEVEL3 )
        lightLevel = 3;
    else if ( photoCellLevel < PHOTOCELL_LEVEL4 )
        lightLevel = 4;
    else if ( photoCellLevel < PHOTOCELL_LEVEL5 )
        lightLevel = 5;
    else if ( photoCellLevel < PHOTOCELL_LEVEL6 )
        lightLevel = 6;
    else if ( photoCellLevel < PHOTOCELL_LEVEL7 )
        lightLevel = 7;
    else
        lightLevel = 8; // Very bright

    // Only update the display light level if there is actually a change (to reduce costly I2C traffic)
    if ( lightLevel != lastLightLevel )
    {       
        // if a large change, use a smoothing function (average) to reduce sharp/large changes
        if ( abs( lightLevel - lastLightLevel ) > 1 )
            lightLevel = ( lightLevel + lastLightLevel ) / 2;
            
        lastLightLevel = lightLevel;
                
#ifdef OPT_GEAR_LEDS                  
        forceLedUpdate = true; // Force update of LEDs
#endif        
         
#ifdef LCD_TYPE_NHD        
        lcd.setBacklight( lightLevel );
#endif        
    }    
  
#ifdef OPT_SHOW_LIGHT_LEVEL
    lcd_print_at(LCD_ROW_BACK_LIGHT, LCD_COL_BACK_LIGHT, lightLevel );  
#endif    
}

/// ----------------------------------------------------------------------------------------------------
/// Reads the current photo cell level from the voltage divider circuit (3K-11K : 10K), using Arduino ADC
/// ----------------------------------------------------------------------------------------------------
void readPhotoCellAnalog()
{
    photoCellLevel = ( short ) analogRead( ANALOGPIN_PHOTCELL );    // read the input pin for Photo Cell Level
}

// ----------------------------------------------------------------------------------------------------
/// Reads the current gear position level from the voltage divider circuit (2:1, 10V -> 5V), using Arduino ADC
/// ----------------------------------------------------------------------------------------------------
void readGearPositionAnalog()
{
    gearReadError = true; // Assume read had errors, by default
   
    int rawValue = analogRead( ANALOGPIN_GEAR_POSITION );
        
    float currentGearPositionVolts = GEAR_VOLT_DIVIDER * vcc * ( rawValue / 1024.0f );    // read the input pin for Gear Position
    // Constrain the input reading, to reduce errors
    currentGearPositionVolts = constrain( currentGearPositionVolts, 0.01f, 5.0f );
    
    if ( abs( currentGearPositionVolts - gearLevelRunAvg.getAverage() ) > 0.5f ) // big change, probably a real gear shift
    {
        gearLevelRunAvg.trimToValue( currentGearPositionVolts );
    }
    else // small change
    {    
        // Recalc average volts
        gearLevelRunAvg.addValue( currentGearPositionVolts );
    }

    // Use the average gear volts
    gearPositionVolts = gearLevelRunAvg.getAverage();
    
    determineCurrentGear();
    
    gearReadError = false; // Clear read error - we made it here
}
// []     0.44 -   4/21/2012 + Restored VREF self learning mechanism

// ----------------------------------------------------------------------------------------------------
/// Determins the current gear from the gear position volts
/// ----------------------------------------------------------------------------------------------------
void determineCurrentGear()
{
     short lastTransientGear = transientGear;

     // Calculate fixed gear position volts
     float fixedGearPositionVolts = gearPositionVolts;
     
     if ( IsBetween( fixedGearPositionVolts,  GEAR1_FROM_VOLTS, GEAR2_FROM_VOLTS ) )
         transientGear = 1;
     else if ( IsBetween( fixedGearPositionVolts, GEAR2_FROM_VOLTS, GEAR3_FROM_VOLTS) )
         transientGear = 2;
     else if ( IsBetween( fixedGearPositionVolts , GEAR3_FROM_VOLTS, GEAR4_FROM_VOLTS ) )
         transientGear = 3;
     else if ( IsBetween( fixedGearPositionVolts, GEAR4_FROM_VOLTS, GEAR5_FROM_VOLTS ) )
         transientGear = 4;
     else if ( IsBetween( fixedGearPositionVolts, GEAR5_FROM_VOLTS, GEAR6_FROM_VOLTS ) )
         transientGear = 5;
     else if ( IsBetween( fixedGearPositionVolts, GEAR6_FROM_VOLTS, GEARN_FROM_VOLTS ) )
         transientGear = 6;
     else if ( IsBetween( fixedGearPositionVolts, GEARN_FROM_VOLTS, GEARN_TO_VOLTS ) )
         transientGear = GEAR_NEUTRAL;
     else
         transientGear = GEAR_ERROR; // Default: Error
         
     // If transient gear has changed, do not allow it to stabilize
     if ( lastTransientGear != transientGear )
     {
         // Reset the transient start counter
         transientGearStartMillis = millis();
         lastTransientGear = transientGear;
     }
     else // Transient gear is the same since last time
     {
         int deltaTransientMillis = millis() - transientGearStartMillis;
         // check if it was stable long enough
         if ( deltaTransientMillis > MIN_TRANSIENTGEAR_INTERVAL )
         {
             // Make transient gear change a stable gear change
             gear = transientGear;

             transientGear = GEAR_ERROR;
         }
     }
}
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

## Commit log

2011-12-04 Initial revision
    [Mk1B Prototype V0.7.fz]
2011-12-05 0.11 - Added gear led logic in software, re factored code to use ISR for main board blink and gear neutral blinking led, changed welcome screen
2011-12-06 Fixed inaccurate dimensions, added measures, spaced 5mm LED holes properly
    [LED Case 2.skp]
2011-12-06 Added 2 side holes (4mm/1.0mm pitch) All 4 sides holes are lengthen to 13mm instead of 10mm Colorized back and side surfaces Added more distance
    [LED Case 2.skp]
2011-12-06 Added more dimensions, removed some unneeded ones
    [LED Case 2.skp]
2011-12-08 Added back cover
    [LED Case 2.skp]
2011-12-09 Runs stable on Arduino 00023
2011-12-09 ==> Fixed TimedAction.h Original code changed by Yuval Naveh, 12/9/2011, to allow compilation on Arduino 1.0. WProgram.h was been removed from Arduino 1.0, and instead there is a header arudino.h
2011-12-09 Added the LED library (originally from Wiring) Adopted to work on Arduino, added default constructor (parameterless, works on default Arudino LED port)
2011-12-10 V0.14: + All LED control was changed to use the LED Library (modified by YN, setState() added ) + Add force LCD update every 15 seconds (workaround to LCD clearing screen from time to time) + Fixed T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
2011-12-10 + Changed custom Timer ISR to TimerOne library + Refactored all constants and variables to Stromputer.h header file
2011-12-10 TimerOne - Library for timer ISR Added to original library: keywords.txt and ISRBlink example
2011-12-10 Fine tuned gear voltage maps
2011-12-11 Fixed coding conventions Code Refactoring
    [Stromputer.h]
2011-12-11 Patched to support Arduino 1.0 as well as 0023
2011-12-11 Changed default back light to level 4 Fixed gear 1 mapping to 0V (workaround to V-Storm behavior when motorcycle engine is off but switch is on, before First moving to N)
    [Stromputer.h]
2011-12-11 Patched to support Arduino 1.0 as well as 0023 (Wire method names changed from receive, send to read, write)
2011-12-11 Compiles under Arduino 1.00, instead the older Alpha 0023
2011-12-11 Upgraded from Arduino 0023 to 1.0 Arduino changed sketch extension from .pde to .ino
2011-12-24 Fixed temperature reading and error handling (I2C recovery)
    [Stromputer.h, Stromputer.ino]
2011-12-25 Fixed state logic with PWM - method setValue()
2011-12-25 LEDs are now using PWM and adjust automatically to light sensor Timer1 has been changed to 1KHz (for LED PWM) and as a result timer dividers had to be recalculated (LEDs are now installed in case, in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
2011-12-31 Fixed force update mechanism, bug with neutral blink
    [Stromputer.h, Stromputer.ino]
2012-01-01 Updated to reflect actual placements of DS1631 and I2C resistors on shield's PCB
2012-01-01 Uses actual placed resistor values Updated to reflect actual placements of DS1631 and I2C resistors on shield's PCB
2012-01-01 Arduino under seat enclosure
2012-01-02 Fixed power components after actual placement on PCB (pre soldering)
2012-01-02 Fixed bug with Power GND Jumper 1
2012-01-08 Added RAM Mount Costs
    [Stromputer BOM.xlsx]
2012-01-09 Obsolete, irrelevant
    [Mk1B Prototype V0.7.fz]
2012-01-14 Updated descriptions, fonts
    [Stromputer BOM.xlsx]
2012-01-14 Fixed incorrect documentation of wiring
2012-01-15 0.25 - Added initial EEPROM configuration (read/write). Currently just TEMPERATURE MODE
2012-01-21 Fixed I2C Error Handling, more EEPROM configurations
    [Stromputer.h, Stromputer.ino]
2012-01-22 Fixed ISR disabled issue (while serial input was processed) adjusted LED brightness - were too dim Code refactoring
    [Stromputer.h, Stromputer.ino]
2012-01-30 ** Fully Operational on motorcycle ** Minor adjustments to gear zones
2012-02-04 Fixed transient/random gear jumps by adding transient suppression (time based)
    [Stromputer.h, Stromputer.ino]
2012-03-31 + Fixed ADC measuring error (battery and on-board temperature). VCC is not 5.0V and can change. Internal volt reference (1.1V) is used as a reference + Using RunningAverage library for smoothing read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
    [Stromputer.h, Stromputer.ino]
2012-03-31 A library that supports Dallas Temperature sensor
2012-04-06 Fixed bug with Serial buffer overflow - strings are shorter and stored in EPROM instead of RAM (using F() macro) DS18B20 prototype connected and tested
    [Stromputer.h, Stromputer.ino]
2012-04-07 Added error detection to DS18B20
    [Stromputer.h, Stromputer.ino]
2012-04-08 Updated wirings: 1. Added OneWire on Port D4 2. Replaced Gear voltage divider resistors and cable 3. Replaced CDs cable
2012-04-12 DS18B20 temperature sensor is functional
2012-04-13 Fixed gear ADC voltage divider
    [Stromputer.h, Stromputer.ino, TestA3.ino]
2012-05-03 Gen2 Initial costs
    [Stromputer BOM.xlsx]
2012-12-15 Fine tuned LED factors
2012-12-16 Updated components for V2
    [Stromputer BOM.xlsx]
2012-12-29 Changed LCD initialization constructor for LiquidCrystal devices
2012-12-29 + LCD print refactoring (using lcd_print_at macro) + DS1631 is now a mode, and disabled by default (it was used in V1, but not in V2)
2012-12-31 Fixed: Only set LCD Backlight level for NHD modules
    [Stromputer.ino]
2012-12-31 Fixed: Incorrect order of backlight
    [Stromputer.ino]
2013-01-05 Fixed: works with YwRobot LCD (compatible with LiquidCrystal)
    [Stromputer.h, Stromputer.ino]
2013-01-05 Fixed lcd_print_at macro: NHD LCD::setCursor has row, col, unlike LiquidCrystal which is col, row
    [Stromputer.h]
2013-01-16 Updated: Added posi-tap and more descriptions
    [Stromputer BOM.xlsx]
2013-01-16 Added I2C Pull up resistors
    [Stromputer BOM.xlsx]
2013-01-19 Using VCC for ADC calculations (instead of hard coded 5V)
2013-02-03 Initial draft version
    [Stromputer V2.sch]
2013-02-03 FW: 1.0.7
    Changes:
    1. Added compilation flag option flag - OPT_SHOW_LIGHT_LEVEL. When defined shows the current light level as a digit next to the BATT label. Undefined by default.
    2. Changed compilation flag DEBUG_PRINT_GEARVOLTS -> OPT_SHOW_GEARVOLTS (Show gear volts above current gear, instead of the GEAR label, undefined by default, very useful for debugging)
    3. Fixed initialization of onboard DS1631 I2C temp sensor (for V1, N/A for V2)
    [Stromputer.h, Stromputer.ino]
2013-02-07 Added power supply capacitors
    [Stromputer V2.sch]
2013-02-07 Full schematic
    [Stromputer V2.sch]
2013-02-07 Updated schematic diagram (V2)
    [Stromputer.fzz]
2013-02-07 Fit in A3
    [Stromputer V2.sch]
2013-02-08 Gear LEDs are now an option, enabled by the OPT_GEAR_LEDS #define SHOW_WELCOME option changed to OPT_SHOW_WELCOME
2013-02-08 Fixed issue with schematic - D11 is PWM, not D12
    [Stromputer V2.sch]
2013-02-10 Originally Stromputer V3_1
    [Stromputer V3.sch]
2013-02-10 Originally V3_2
    [Stromputer V3.sch]
2013-02-10 Originally V3_4
    [Stromputer V3.sch]
2013-02-10 Deleted unneeded versions of schema and PCB
    [Stromputer V3_1.sch, Stromputer V3_2.sch]
2013-02-10 Added RGB LED Moved Enclosure Mounting Holes Added outline of Hammond RP1135 to Documentation Layer 2
    [Stromputer V3.sch]
2013-02-11 Updated board outline
2013-02-16 Fixed Neutral From to range to 4.85V (On another test bike 6th gear got to 4.73V). Also N should be 5.0V on all bikes (+-0.1V)
    [Stromputer.h]
2013-02-18 Added PDF versions of PCB and Schematic
2013-03-11 Fixed back compatibility with V1 (Could not compile with DS1631 option)
    [Stromputer.h, Stromputer.ino]
2013-04-01 V3 BOM
    [Stromputer BOM.xlsx]
2013-04-04 Fixed some connection issues with GPS, BATT and GND connections
    [Stromputer V2.sch]
2013-04-14 Update V3 components
    [Stromputer BOM.xlsx]
2013-06-15 V3 Final
    [Stromputer BOM.xlsx]
2013-07-13 Fix error with enclosure part #. It should be RP1135C, not RP1085C
    [Stromputer BOM.xlsx]
2013-07-14 Renamed folder PCB Design to Schematics
    [Stromputer V2.sch, Stromputer V3 PCB Artist BOM.xls, Stromputer V3.sch]
2013-07-20 SOFTI2C support for LCD modules to workaround Stromputer V3 pin layout issues (PCB was layout for Nano V2.2 instead of V3)
2013-07-20 SOFTI2C support for Stromputer V3 pin layout issues (PCB was layout for Nano V2.2 instead of V3)
    [Stromputer.h, Stromputer.ino]
2013-07-28 Fixed: SDA and SCL ports on PCB were reversed due to reverse analog pin layout assignment. Now A2 (on PCB labeled as A5) is for SCL and A3 is (on PCB labeled as A4) for SDA
2013-08-22 Added option to reverse gear led order, for installations that use the LEDs on the front of the PCB, instead of the back (see define: V3_USE_LEDS_PCBFRONT)
2013-10-17 Replaced Yellow LED part #
    [Stromputer BOM.xlsx]
2019-11-17 Added image of Stromputer V1 installed on the motorcycle
